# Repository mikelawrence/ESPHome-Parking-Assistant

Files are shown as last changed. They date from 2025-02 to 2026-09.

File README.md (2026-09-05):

# ESPHome Parking Assistant

From early on I learned that parking the car in the garage was a problem the needed to be solved. My Dad solved his problem with a piece of styrofoam hanging from the ceiling. When it touched the windshield you knew to stop. This was very important because the lawn mowing equipment was in front of the car. Crunch time was inevitable, don't ask me how I know. 

I recently moved and the problem became an issue again. Not because there was a crunch time incident but because we needed as much room as possible in front of the car. Having to get out of the car multiple times to make sure the door won't hit the car was a pain. So I did some searching on Youtube and found this [video](https://www.youtube.com/watch?v=HqqlY4_3kQ8) from ResinChem Tech. I really liked his use of a RGB LED strip to indicate position and when to stop. There is a ton of information so watch the whole video.1

***So yes this project is a complete ripoff of his idea!*** But I wanted to do several things different. First I wanted to use ESPHome. Second I really like designing my own hardware. And third I want to keep learning how to use Fusion 360 to design 3D printed stuff.

## Design Decisions

### ESP32 and ESPHome

ESPHome is closely aligned with Home Assistant. In fact they are the same company. Home Assistant uses ESPHome for some of their hardware like the [Home Assistant Voice Preview Edition](https://www.home-assistant.io/voice-pe/) or [Bluetooth Proxy](https://esphome.io/components/bluetooth_proxy.html). I chose a newer ESP32-S3 for this design which also has Bluetooth support. The newer ESP32's work better with the ESP-IDF framework as opposed to the default Arduino framework. Not everything is supported in the ESP-IDF, particularly several of the RGB LED libraries but the ESP32 RMT LED Strip library works well once you make sure have enough RMT memory allocated.

### USB-C Power Delivery

I liked the idea of using RGB LED Pixels since ESPHome supports these directly without custom code. I wanted a flexible power supply for driving the RGB LED Pixels both in the power capacity and voltage. I've been using a MagWLED driver for driving RGB LED pixels for a while now and I really like it's approach to using USB-C PD (Power Delivery) to select between 5V and 12V. The USB-C PD 2.0/3.0 specification supports currents greater than 3A but will need a USB-C Power Cable with E-Marker and a USB-C PD Power Source that supports these higher currents. I went with the simpler and more supported max 3A. The USB-C PD 2.0/3.0 specification will negotiate several fixed voltages at 3A: 5V-15W, 9V-27W, 12V-36W, 15V-45W and 20V-60W. 12V-36W PD is less common in chargers but 9V-27W is always available. 12V RGB LED Pixels will usually run on 9V, the difference in LED brightness is not that noticeable and may make your LED live longer. To handle the USB-C PD negotiation I chose the STUSB4500 from ST Microelectronics. This guy will support negotiate all of the USB-C PD 2.0/3.0 specification but this design will support only the following: 5V-15W, 9V-27W or 12V-36W. The STUSB4500 will be configured to support 12V-36W with a fallback of 9V-27W or just 5V-15W

The STUSB45000 will negotiate 20V by default if the USB-C PD Power Source supports it so our power supplies must support an input voltage range of 5V - 20V. The STUSB4500 uses an external pass transistor to enable V<sub>BUS</sub> at higher currents and voltages when PD is properly negotiated. Until the configured PD is properly negotiated this pass transistor is turned off. Using USB-C PD to provide a variable input voltage from USB-C PD is elegant but if 9V-27W or 12V-36W PD is configured 3.3V is still needed for the ESP32 and 5V for the TFMini. This means two DC/DC converters are necessary, one 3.3V @ 600mA to support primarily the ESP32-S3 chip and 5V @ 1.0A primarily for the TFMini Plus sensor. 

The 3.3V power supply will always have an input voltage greater than 3.3V. I could use a linear regulator but I wanted to get more experience designing efficient DC/DC converters so I chose the TPS560430 SIMPLE SWITCHER® 4-V to 36-V, 600-mA Synchronous Step-Down Converter. The 3.3V power supply is connected directly to the USB connector and will power the ESP32-S3 immediately. If you connect this board to a older USB 2.0 power source you may only get 5V at 500mA. This is enough to get the ESP32-S3 running without violating the 500mA max requirement.

For the 5V @ 1A power supply it's input voltage can be 5V so a regular step-down will not work. I chose the TPS552872, 36-V, 4-A, Fully Integrated Buck-boost Converter also from TI. This converter will switch to boost mode when the input voltage is 5V and still operate correctly. This power supply must be connected to the V<sub>BUS</sub> pass transistor and not directly to the V<sub>BUS</sub> on the USB connector. Doing so would exceed the 500mA maximum when connected to a USB 2.0 power source. Some USB 2.0 Power Sources support more than 500mA but the specification states 500mA maximum. So until PD is properly negotiated the V<sub>BUS</sub> to the RGB LED pixels and the 5.V power supply are not enabled.

An INA228 85-V, 20-Bit, Ultra-Precise Power/Energy/Charge Monitor With I2C Interface device is used to monitor both energy and power consumption. Energy consumption is a better metric than instantaneous power for understanding actual device usage. Just look at what the power company uses to bill you (kWh).

### TFMini Plus

ResinChem Tech compared multiple distance sensors in his video. He settled on the TFMini-S sensor. I also chose a TFMini sensor but went with the TFMini Plus because it was in a more durable package with a lens cover. The spot size is different but in my tests this sensor worked just fine. This sensor can use a UART or I2C interface. The default UART interface can be set to automatically send measurements at a specified rate while the I2C must be setup with a UART command first and requires polling. The TFMini Plus requires 5V power but uses 3.3V logic levels.

### RGB LED pixel interface

This board only supports RGB LED pixels that have a single data line for communication. SPI pixels are NOT supported. RGB LED pixels requires 5V logic level on the data and while many will tell you that it will work just fine with 3.3V logic I prefer to be more conservative. After doing some [research](https://electricfiredesign.com/2021/03/12/logic-level-shifters-for-driving-led-strips/) I chose the TC4427V MOSFET Driver. It can source/sink 1.5A; definatley help long cable runs. Note the V temperature range option. The V option does more that expand the temperature range it also lowers V<sub>IH</sub> from 2.4V to 2.0V. This give plenty of margin for 3.3V ESP32 with a worst case V<sub>OH</sub> of 0.8\*VCC or 0.8\*3.0=2.4V.

## Enclosure

The enclosure is designed to mount on [Elfa](https://www.containerstore.com/s/elfa/garage-plus-by-elfa/garage-plus-by-elfa-predesigned-spaces/garage-plus-7-tier-6-wall-shelving-solution/123d?productId=11023646) wire shelving. I used [Autodesk Fusion](https://www.autodesk.com/products/fusion-360/overview) to design this enclosure. I'm a novice with this tool but I'm always looking to improve. For this design I tried out a few new features of Fusion, namely Rendering and Animation.

<p align="center">
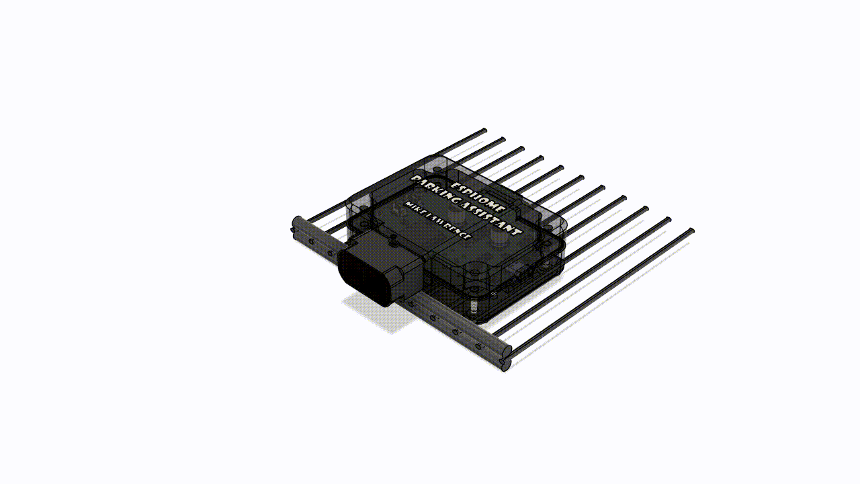
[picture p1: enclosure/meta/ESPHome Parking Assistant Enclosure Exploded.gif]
     <br />
    Exploded View of Enclosure
</p>

## PCB

This 4-layer board is designed with [KiCad](https://www.kicad.org/). I been using this free tool for a while and it just keeps getting better and better.

<p align="center">
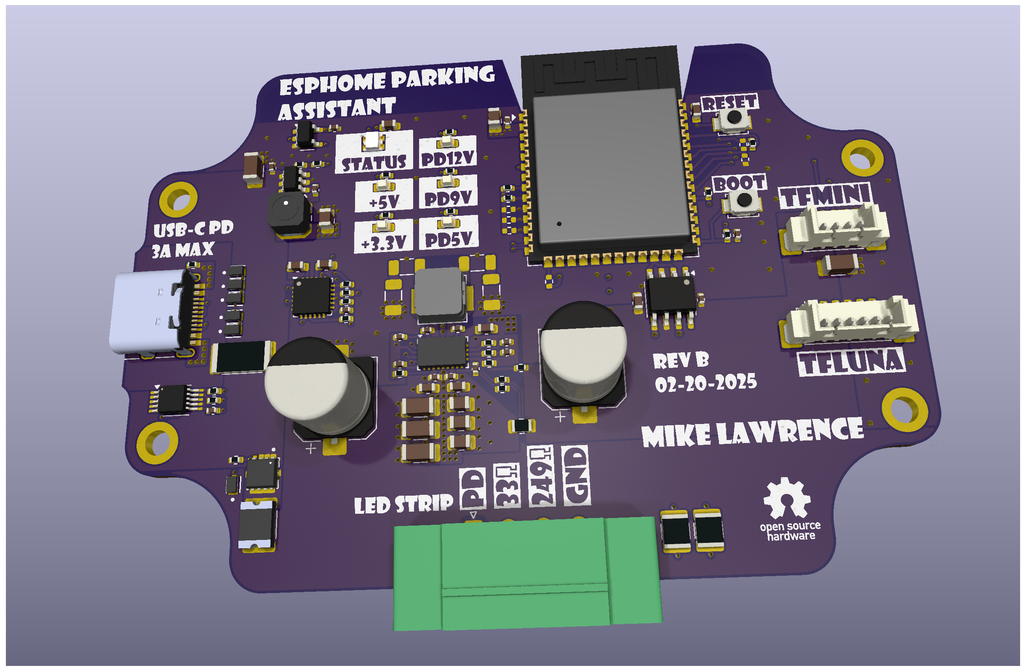
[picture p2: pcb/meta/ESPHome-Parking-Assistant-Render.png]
     <br />
    3D Render of ESPHome Parking Assistant PCB
</p>

## Operation

### LED status

There are six LEDs on the PCB to indicate status.

* **Status:** If dark something is misconfigured or damaged. If blue PS was successfully negotiated. If Power Delivery failed but +5V is available on VBUS the LED will be red. Generally you shouldn't be using the connected power brick for lighting up the LEDs unless you know it can support the power requirements. Keep in mind this board was designed for USB-C Power Delivery so why don't you connect one.
* **+5V:** Will be green when the +5V power supply is on. This power supply comes from VBUS and supports 4.5V - 22 V inputs.
* **+3.3V:** Will be green when the +3.3V power supply is on. This power supply is always on when connected to USB-C or USB 2.0 power sources. If the LED is off then the USB is not connected or there is a failure.
* **PD5V:** Will be blue when PDO1 (+5V) has been negotiated.
* **PD9V:** Will be blue when PDO2 (+9V) has been negotiated.
* **PD12V:** Will be blue when PDO3 (+12V) has been negotiated.

> [!NOTE]
> Only one of the three PD LEDs will be lit at a time. 

### Connecting RGB LED strips

The mate to the on-board terminal strip connector is Phoenix Contact 1847071.

The LED connector has 4 wires.

* **PD**: This is the LED voltage wire, often labeled 12V+ or 5V. This PCB supports up to 3A at 5V, 9V or 12V as long as the correct USB-C PD Power Source is connected.
* **33Ω**: This is data line with a 33Ω series resistor. Use this for longer wire runs over 10ft.
* **249Ω**: This is the same data line but with a 249Ω series resistor. Use this for shorter wire runs.
* **GND**: This is minus side of the LED voltage.

> [!NOTE]
> Connect only one of 33Ω or 249Ω to your LED Strip.
> [!NOTE]
> Many 12V RGB LEDs run just fine on 9V. In fact running at 9V may extend their life expectancy.

## Configuration

### STUSB4500 Configuration

> [!CAUTION]
> When configuring the STUSB4500 for the first time you should realize its default configuration will allow up to 20V on V<sub>BUS</sub>. This PCB works fine with 20V but this voltage is passed to the LED connector. Make sure your LEDs are disconnected before configuring the STUSB4500.

1. Uncomment either the 12V LED section or the 5V LED section in the ```config.yaml``` file.
2. Uncomment ```flash_nvm: true``` in the ```config.yaml``` file
   You should see the following messages in your log.

     ```log
     [00:10:03][C][stusb4500:112]: STUSB4500:
     [00:10:03][E][stusb4500:119]:   NVM has been flashed, power cycle the device to reload NVM
     ```

   If you forgot to uncomment ```flash_nvm: true``` to the configuration you will see an error in the log.

     ```log
     [00:06:27][C][stusb4500:112]: STUSB4500:
     [00:06:27][E][stusb4500:114]:   NVM does not match current settings, you should set flash_nvm: true for one boot
     [00:06:27][C][stusb4500:130]:   PDO3 negotiated 20.00V @ 1.00A, 20.00W
     ```

3. Power cycle your board. Make sure ```NVM matches settings``` is present in the log and that one of your PDOs was negotiated. The example below shows the result of the 12V LED configuration.

   ```log
   [00:00:19][C][stusb4500:112]: STUSB4500:
   [00:00:19][C][stusb4500:116]:   NVM matches settings
   [00:00:19][C][stusb4500:130]:   PDO3 negotiated 12.00V @ 3.00A, 36.00W
   ```

4. If you selected the 12V LED config section you should see either the PD12V LED or PD9V LED lit. PD5V should be lit if you selected the 5V LED section. 

5. The STUSB4500 component does check to see that the NVM is indeed different before flashing the NVM but it is prudent to remove the ```NVM matches settings``` after it is clear the STUSB4500 is working as intended. You don't want to wear out your NVM.

### Installation

Place the enclosure so the the sensor hits as flat an area as possible. For my car this is the license plate. You may have to play different options for best performance. My experience was pretty much place and forget. It just

Now the sensor is placed, close the garage door with no car present. Home Assistant will show the measured distance. Convert to cm if necessary and subtract half of ```door_tolerance``` set ```door_distance``` to this value.

Next we set ```start_distance``` to ```door_distance``` - 25 and install the current config.

For the final setting, open the garage door and park your car where you want it. Set ```stop_distance``` using the converted distance, if necessary, from Home Assistant and again install the current config.

You now have a basic setup. Testing is in order. Back the car first and then start moving back in. Watch the LED strip light turn on and start movig toward the center as you move the car in. Stop as soon as the LED strip light turn green. Check the parking position and adjust ```stop_distance``` a little bit. As you repeat this test you will get a feel for how much to change ```stop_distance``` to get the car to stop in the right place.

## Status

* PCB Rev B: Fabricated by JLCPCB and tested. The 5V DC/DC converter issues for Rev A are resolved. This board is fully operational.
* PCB Rev A: Fabricated by JLCPCB and tested. Worked well enough to write the code for ESPHome including the new STB4500 and TFMini components. The main problem with Rev A was the 5V DC/DC converter won't start at 5V. This was technically in the datasheet but there was also a minimum operating voltage the was well below 5V input. I didn't realize that you need to apply more than 5V for the regulator to start working and then you can lower the input to 5V. Not exactly what I needed.
* Enclosure: Printed and successfully tested on Rev A. Rev B has been fully tested.

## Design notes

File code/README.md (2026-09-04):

# ESPHome Parking Assistant Code

Use the ```config.yaml``` file above to configure the ESPHome Parking Assistant in ESPHome.

## STUSB4500 and TFMini External Components

ESPHome doesn't directly support either the STUSB4500 or the TFMini devices. I wrote code that allows ESPhome to support these devices using [External Components](https://esphome.io/components/external_components.html).

For a more detailed description of these components have a look at the repositories [TFMini](https://github.com/mikelawrence/esphome-component-tfmini) and [STUSB4500](https://github.com/mikelawrence/esphome-component-stusb4500).

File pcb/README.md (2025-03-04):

# ESPHome Parking Assistant PCB
<p align="center">
     <br />
</p>

The PCB is designed in [KiCad](https://www.kicad.org/). Fabrication and Assembly is tuned toward [JCLPCB](https://jlcpcb.com/). The production folder has everything you need for JLCPCB to send you fully assembled boards.

## Schematic
<p align="center">
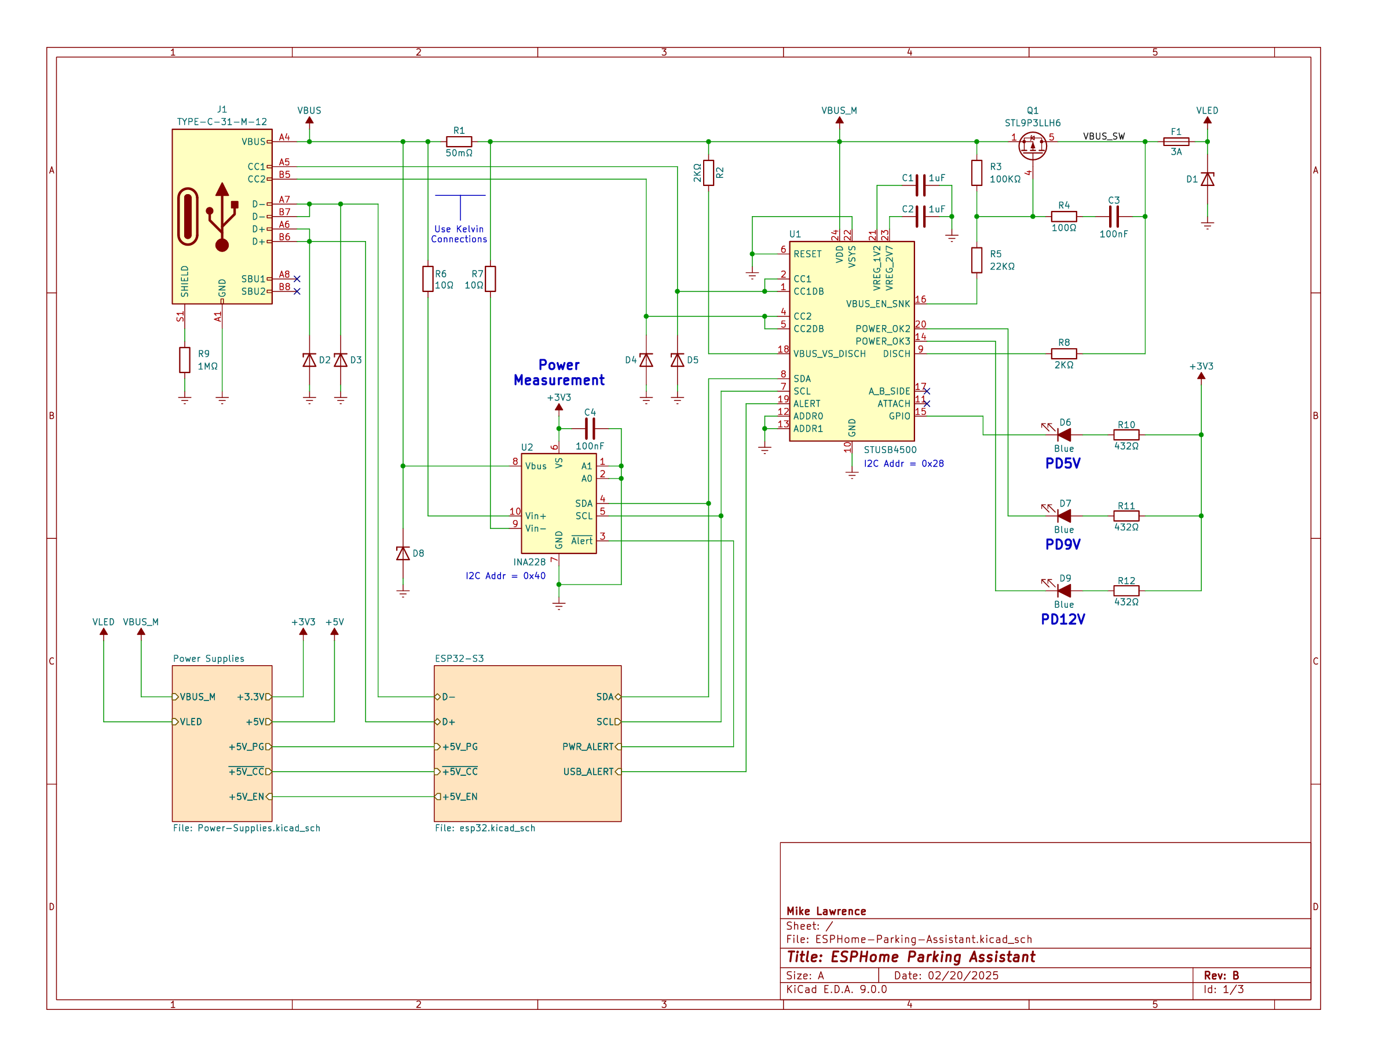
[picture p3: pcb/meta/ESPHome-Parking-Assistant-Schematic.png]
     <br />
</p>

### Do Not Populate (DNP) Notes
* ```C9```, ```C10```, ```R16``` and ```R17```: These components are an optional snubber used to reduce EMI. Not needed.
* ```R31``` and ```R32``` are pullups for open drain outputs. If these pins are used the 10K pullup will be enabled on the ESP32 input pins.
* ```R33``` and ```R35``` are pullups for the I<sub>2</sub>C Bus. By default the internal ESP32 pullups are enabled.
* ```R34``` and ```R36``` can be used to pullup or pulldown the ```CONFIG``` pin on the TFLuna connector. For now this is not necessary because the code only supports the UART interface on the TFLuna and leaving ```CONFIG``` floating will enable the UART. 
* ```R26``` is used to compensate for cable droop. Not currently used.

## Bill of Materials
<p align="center">
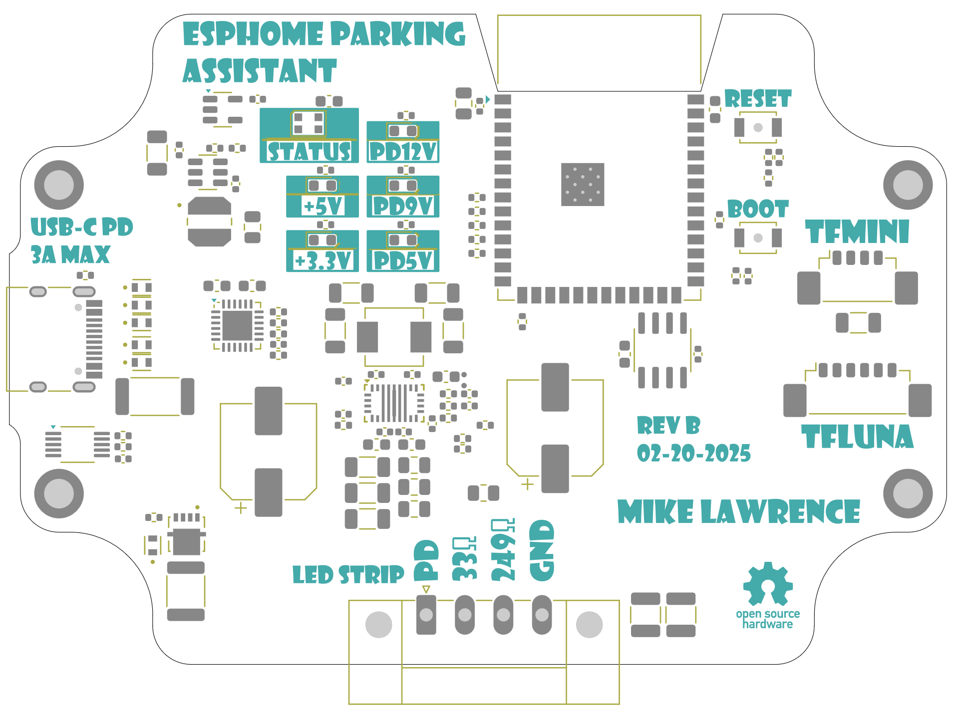
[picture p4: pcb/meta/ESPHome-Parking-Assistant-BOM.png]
     <br />
    Interactive BOM
</p>

## PCB Info
* 4 layer to support an additional ground plane and signal layer to reduce plane interruptions on the outer layers.
* Dimension are 85mm X 59mm.
* Requires oven reflow or hot air to assemble some components.
* Supports TFMini Plus, TFMini-S and TFLuna Range Finder Sensors. Enclosure is designed for TFMini Plus Sensor.

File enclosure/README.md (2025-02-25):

# ESPHome Parking Assistant Enclosure

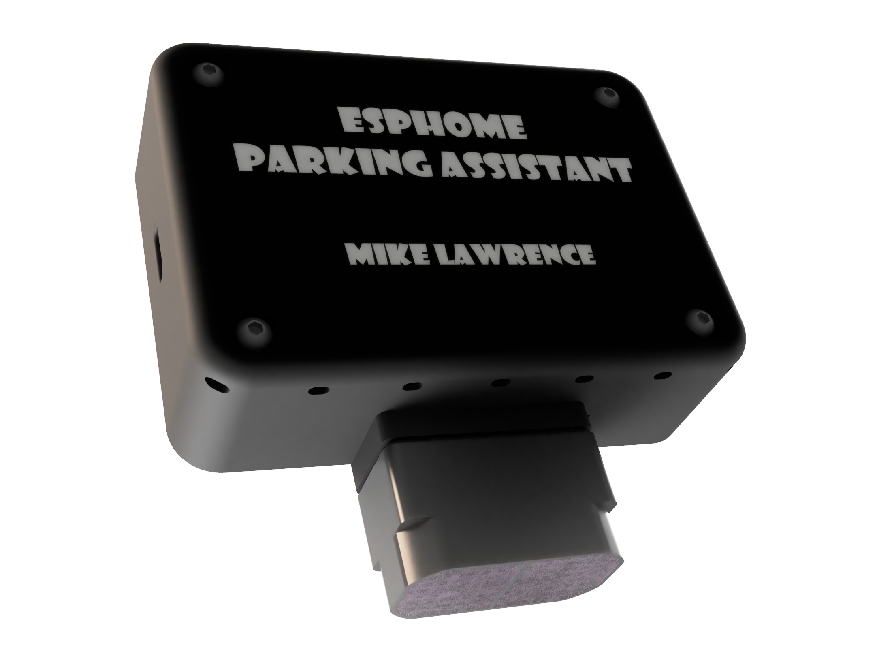
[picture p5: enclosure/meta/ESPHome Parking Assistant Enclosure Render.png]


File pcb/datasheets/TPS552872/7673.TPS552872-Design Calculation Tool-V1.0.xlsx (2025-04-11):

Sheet: Design Calculation
Design Tool for TPS552872
V1.0 (08/01/2023)
This tool is designed to aid the user in designing the TPS552872 buck-boost converter. Refer to TPS552872 datasheet for detail design precedure and all equations.
 |  | User input value
 |  | Calculated value
 |  | No use or internal value
Description | Value | Units | Instructions/Comments | Schematic
Component Value
Vin(min) | 4.5 | V | >=3.0V
Vin(max) | 22 | V | <=36V
Vout | 5.00 | V | Must be lower than or equal to 22V
Iout(max) | 1.5 | A | Maximum output current
VCC | Internal |  | Select internal VCC or use external VCC power supply
EXTVCC | High |  | EXTVCC pin input logic status
Switching Mode at light load | FPWM |  | Select Forced PWM or Auto PFM mode at light load
MODE | High |  | MODE pin input logic status
R5 recommended | 100000.0 | Ω | Up resistor value of the extenral feedback resistor value. It is recommended to 100kΩ
R6 recommended | 31578.9 | Ω | Bottom resistor value of the external feedback resistor divider
Iout(limit) | 2 | A | Output current limit setting
R1 | 25.0 | mΩ | Output current sensing resistor
ΔIout(Cout_rms) | 0.50 | Arms | The equivalent output capacitor current ripple spec must be higher than this value.
ΔIin(Cin_rms) | 0.75 | Arms | The equivalent input capacitor current ripple spec must be higher than this value
f(sw) | 403000 | Hz | Typical switching frequency
R2 recommended | 48677.79156 | Ω | Switching frequency setting resistor
Frequency dithering f(mod) | 725 | Hz | Modulation frequency for spread spectrum
C8 recommended | 1.011982717e-08 | F |  | Register Setting
ΔVout(pk-pk) | 0.05 | Vpp | Maximum desired output ripple solely due to output capacitance (ignores ESR)
Cout(min) recommended | 7.444168734e-06 | F | Minimum output capacitance needed for Vout ripple requirement
C2 actual | 3.3e-05 | F | Effective ceramic capacitance at VOUT. Need to consider the derating with DC bias voltage
C3 actual | 0.000189 | F | Effective electrolytic capacitance. Need to consider the derating with DC bias voltage
ESR of C3 | 0.185 | Ω | Equivalent ESR if multiple high ESR electrolytic capacitors in parallel
ΔVin(pk-pk) | 0.05 | Vpp | Maximum desired input ripple due to solely to input capacitance at buck mode
Cin(min) recommended | 1.861042184e-05 | F | Minimum input capacitance needed for Vin ripple requirement
Cin actual | 2.3e-08 | F | effective output capacitance. Need to consider the derating with DC bias voltage when using ceramic cap
η estimate | 95.0% |  | Efficiency estimate. Correct it after getting the calculated efficiency
K | 0.5 |  | Fraction of maximum average inductor current that is ripple current (0.2-0.6 typically)
L1 recommended min | 1.272952854e-06 | H | L1's minimum recommended inductance value to meet inductor current ripple ratio at boost mode with Vin_min
L1 actual | 4.7e-06 | H
I(Lrms) max | 1.76 | Arms | Inductor maximum RMS current
I(Lpeak) max | 1.87 | A | The inductor (L1) is recommended to have saturation current rating 30% higher than this value.
I(Laverage) max | 1.75 | A | Inductor average current at minimum Vin.
I(Lvalley) max | 1.64 | A
Average Inductor Limit | 4.0 | A | Desired typical average inductor current limit. ±0.7A tolerance
External CDC voltage ratio | 0 | mV/mV | ΔVout / (VISP-VISN)
R4 recommend | floating | Ω | Recommended R4 for external CDC setting
Loop Compensation Calculation in FPWM CCM mode |  |  |  | Bode Plot
Vin | 12.0 | V | Check both buck and boost mode by changing Vin and Vout. The loop must have enough phase margin and gain margin
Vout | 5.0 | V
Buck or Boost? | Buck |  | Calculate open loop compensate at buck mode or boost mode
gm_PS | 17.6 | S | Power stage gm of IL/Vcomp
fp_PS | 215.0742474 | Hz | Power stage pole of Rload and Cout
fz_RHP | No RPHZ | Hz | Right half plane zero in boost mode
fz_ESR | 4551.835924 | Hz | ESR zero of the output cap
f(BW) desired | 10000 | Hz | Should be less than 1/5*fzRPH and 1/10*fsw
gm_EA | 0.00019 | S | Error amplifier gm
R3 recommended | 18473.22145 | Ω
R3 actual | 15000 | Ω | COMP pin has internal 2k resistor in seriese with R3
C7 recommended | 9.362055476e-09 | F | Set the compensation fz = fco/10
C7 actual | 1e-08 | F
fz_COMP | 936.2055476 | Hz | Loop compensation zero frequency
C6 recommended | 3.039509714e-09 | F | The lower zero of the Cout's ESR zero and boost right half plane zero should be cancelled by the R3*(C6*C7/(C6+C7)) pole.
C6 actual | 2.7e-09 | F
fp2_COMP | 4399.78508 | Hz | Have internal 3pF cap between COMP and GND
Efficiency in buck CCM mode or boost CCM mode with maximum Iout
Vin | 5.0 | V | Vin for efficiency estimation at desired Vout and Iout(max)
I(Lrms) | 1.50 | A | Inductor RMS current
I(Lpeak) | 1.50 | A | Inductor peak current
I(Lvalley) | 1.50 | A | Inductor valley current
DCR of L1 | 0.071 | Ω | Inductor series resistance per inductor datasheet
Buck HSFET Rdson | 0.014 | Ω | Buck HSFET on-resistance in TPS552892 is 14mΩ at 25°C. Temperature coefficient is 0.4%/°C. Correct it when at high Tj
Buck HSFET rise time | 1.3e-08 | s | Estimate of SW1 node 10-90% rise time from measurement
Buck HSFET fall time | 1.3e-08 | s | Estimate of SW1 node 10-90% fall time from measurement
Buck LSFET Rdson | 0.022 | Ω | Buck LSFET on-resistance in TPS552892 is 22mΩ at 25°C. Temperature coefficient is 0.4%/°C. Correct it when at high Tj
Buck LSFET dead time | 1e-08 | s | Dead time during the switching
Buck LSFET diode voltage | 0.8 | V | Estimate of body diode voltage of the HSFET
Boost LSFET Rdson | 0.011 | Ω | Boost LSFET on-resistance in TPS552892 is 11mΩ at 25°C. Temperature coefficient is 0.4%/°C. Correct it when at high Tj
Boost LSFET fall time | 9e-09 | s | Estimate of SW node 10-90% fall time from measurement
Boost LSFET rise time | 1.3e-08 | s | Estimate of SW node 10-90% rise time from measurement
Boost HSFET Rdson | 0.01 | Ω | Boost HSFET on-resistance in TPS552892 is 10mΩ at 25°C. Temperature coefficient is 0.4%/°C. Correct it when at high Tj
Boost HSFET dead time | 2e-08 | s | Dead time during the switching
Boost HSFET diode voltage | 1.0 | V | Estimate of body diode voltage of the HSFET
Buck snubber Csnubber | 0 | F | Capacitance of snubber at buck side
Boost snubber Csnubber | 0 | F | Capacitance of snubber at boost side
Rpcb on power path | 2.0 | mΩ | PCB trace resistance on power path from Vin to Vout cap
Rpcb Pd | 4.5 | mW | Power losses on PCB trace
Inductor DCR Pd | 159.75 | mW | Includes losses from DC resistance drop only
Inductor core & AC Pd | 521 | mW | Core and AC loss of inductor. Use inductor vendor's formula to estimate. 521mW is the power loss of XAL7070-472 running at 400kHz with Ilrms=5.32A and Ilripple=2.63A at 400kHz.
TPS552892 Pd | 145.831992 | mW | Power loss on TPS552892
Rsense Pd | 56.25 | mW | Power loss on output current sense resistor
Snubber Pd | 0 | mW | Power loss on snubber
Cout Pd | 0 | mW | Power loss on ESR of the output capacitor in boost mode | 5.1975e-06 | 0 | 0
η - calculated | 89.4% |  | Efficiency at Iout_max
ΘJA | 33 | °C/W | TPS552892 junction to ambient thermal resistance on EVM. The actual ΘJA depends on the PCB design.
TPS552892 temperature rise | 4.8 | °C | The top case temperature of IC is very close to the Junction temperature because ΨJT=0.6°C/W

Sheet: LegalDisclaimer
THIS PROGRAM IS PROVIDED "AS IS". TI MAKES NO WARRANTIES OR REPRESENTATIONS, EITHER EXPRESS, IMPLIED OR STATUTORY, INCLUDING ANY IMPLIED WARRANTIES OF MERCHANTABILITY, FITNESS FOR A PARTICULAR PURPOSE, LACK OF VIRUSES, ACCURACY OR COMPLETENESS OF RESPONSES, RESULTS AND LACK OF NEGLIGENCE. TI DISCLAIMS ANY WARRANTY OF TITLE, QUIET ENJOYMENT, QUIET POSSESSION, AND NON-INFRINGEMENT OF ANY THIRD PARTY INTELLECTUAL PROPERTY RIGHTS WITH REGARD TO THE PROGRAM OR YOUR USE OF THE PROGRAM.
IN NO EVENT SHALL TI BE LIABLE FOR ANY SPECIAL, INCIDENTAL, CONSEQUENTIAL OR INDIRECT DAMAGES, HOWEVER CAUSED, ON ANY THEORY OF LIABILITY AND WHETHER OR NOT TI HAS BEEN ADVISED OF THE POSSIBILITY OF SUCH DAMAGES, ARISING IN ANY WAY OUT OF THIS AGREEMENT, THE PROGRAM, OR YOUR USE OF THE PROGRAM. EXCLUDED DAMAGES INCLUDE, BUT ARE NOT LIMITED TO, COST OF REMOVAL OR REINSTALLATION, COMPUTER TIME, LABOR COSTS, LOSS OF GOODWILL, LOSS OF PROFITS, LOSS OF SAVINGS, OR LOSS OF USE OR INTERRUPTION OF BUSINESS. IN NO EVENT WILL TI'S AGGREGATE LIABILITY UNDER THIS AGREEMENT OR ARISING OUT OF YOUR USE OF THE PROGRAM EXCEED FIVE HUNDRED DOLLARS (U.S.$500).
Unless otherwise stated, the Program written and copyrighted by Texas Instruments is distributed as "freeware". You may, only under TI's copyright in the Program, use and modify the Program without any charge or restriction. You may distribute to third parties, provided that you transfer a copy of this license to the third party and the third party agrees to these terms by its first use of the Program. You must reproduce the copyright notice and any other legend of ownership on each copy or partial copy, of the Program.
You acknowledge and agree that the Program contains copyrighted material, trade secrets and other TI proprietary information and is protected by copyright laws, international copyright treaties, and trade secret laws, as well as other intellectual property laws. To protect TI's rights in the Program, you agree not to decompile, reverse engineer, disassemble or otherwise translate any object code versions of the Program to a human-readable form. You agree that in no event will you alter, remove or destroy any copyright notice included in the Program. TI reserves all rights not specifically granted under this license. Except as specifically provided herein, nothing in this agreement shall be construed as conferring by implication, estoppel, or otherwise, upon you, any license or other right under any TI patents, copyrights or trade secrets.
TI Information - Selective Disclosure. You may not use the Program in non-TI devices.

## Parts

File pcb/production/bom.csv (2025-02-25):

Designator | Footprint | Quantity | Value | LCSC Part #
C1, C14, C2, C25, C35, C37, C39 | 0603 | 7 | 1uF | C15849
C11, C12, C13, C19, C22, C29, C3, C31, C34, C36, C38, C4, C5, C7 | 0402 | 14 | 100nF | C307331
C15, C16, C17, C32, C8 | 0805 | 5 | 22uF | C92814
C18, C23 | CP_Elec_8x10.5 | 2 | 220uF | C178562
C20, C21, C24, C33, C6 | 1206 | 5 | 10uF | C13585
C26 | 0603 | 1 | 4.7uF | C19666
C27, C30 | 0402 | 2 | 10nF | C15195
C28 | 0402 | 1 | 2.7nF | C84704
D1, D4, D5, D8 | TVS_ESDA25P35-1U1M | 4 | ESDA25P35-1U1M | C1974707
D10, D11 | 0603 | 2 | Green | C7496818
D12 | LED_WS2812B-2020_PLCC4_2.0x2.0mm | 1 | WS2812B-2020 | C965555
D2, D3 | TVS_ESDA25P35-1U1M | 2 | ESDA7P60-1U1M | C1975146
D6, D7, D9 | 0603 | 3 | Blue | C7496819
F1 | 1812 | 1 | 3A | C2760295
J1 | USB_C_Receptacle_HRO_TYPE-C-31-M-12 | 1 | TYPE-C-31-M-12 | C165948
J2 | Molex_PicoBlade_53398-0471_1x04-1MP_P1.25mm_Vertical | 1 | 533980471 | C17617036
J3 | Molex_PicoBlade_53398-0671_1x06-1MP_P1.25mm_Vertical | 1 | 533980671 | C277393
J4 | PhoenixContact_MC_1,5_4-GF-3.5_1x04_P3.50mm_Horizontal_ThreadedFlange_MountHole | 1 | Screw_Terminal_01x04
L1 | IND_VLCF4028T-100M1R0-2 | 1 | 10uH | C694593
L2 | L_Vishay_IHLP-2020 | 1 | 4.7uH | C845007
Q1 | TRANS_STL9P3LLH6 | 1 | STL9P3LLH6 | C2969828
R1 | 2512 | 1 | 50mΩ | C375690
R10, R11, R12 | 0402 | 3 | 432Ω | C25113
R13 | 0402 | 1 | 51KΩ | C25794
R14, R2, R8 | 0402 | 3 | 2KΩ | C4109
R15, R5 | 0402 | 2 | 22KΩ | C25768
R18 | 0805 | 1 | 25mΩ | C2767472
R19, R20, R6, R7 | 0402 | 4 | 10Ω | C25077
R21, R29, R3, R30, R37 | 0402 | 5 | 100KΩ | C25741
R22 | 0402 | 1 | 8.2KΩ | C36953
R23 | 0402 | 1 | 15KΩ | C25539
R24 | 0402 | 1 | 31.6KΩ | C226989
R25 | 0402 | 1 | 48.7KΩ | C26981
R27, R28 | 0402 | 2 | 10KΩ | C25531
R38 | 1210 | 1 | 33Ω | C105005
R39 | 1210 | 1 | 249Ω | C874850
R4 | 0402 | 1 | 100Ω | C25076
R9 | 0402 | 1 | 1MΩ | C26083
SW1 | SW_SPST_B3U-1000P-B | 1 | RESET | C231329
SW2 | SW_SPST_B3U-1000P-B | 1 | BOOT | C231329
U1 | QFN-24-1EP_4x4mm_P0.5mm_EP2.7x2.7mm | 1 | STUSB4500 | C2678061
U2 | VSSOP-10_3x3mm_P0.5mm | 1 | INA228 | C2887910
U3 | SOT-23-6 | 1 | TPS560430 | C524782
U4 | VQFN21_RYQ_TEX | 1 | TPS552872RYQR | C22397842
U5 | ESP32-S3-WROOM-1 | 1 | ESP32-S3-WROOM-1 | C2913201
U6 | SOIC-8_3.9x4.9mm_P1.27mm | 1 | TC4427 | C636893
U7 | SOT-23-5 | 1 | SN74LV1T34DBV | C100024

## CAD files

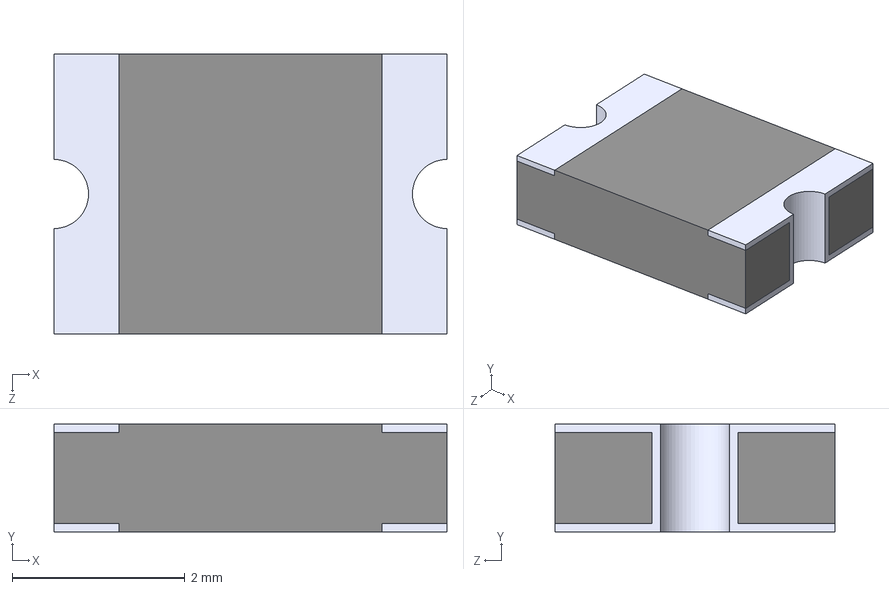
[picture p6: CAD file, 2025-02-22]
pcb/3dmodels/1812_Fuse.STEP
4.55 x 1.25 x 3.24 mm

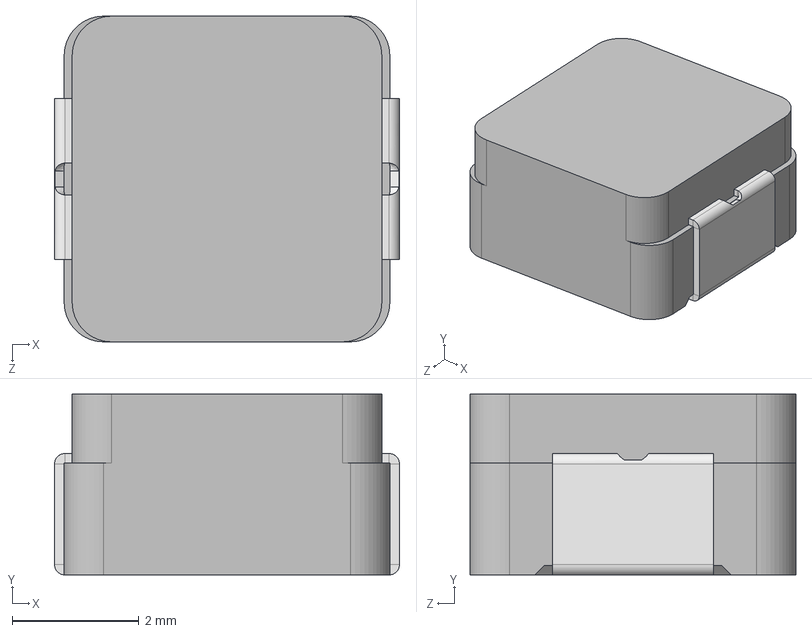
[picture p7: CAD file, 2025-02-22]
pcb/3dmodels/IHLP2020CZ.step
5.45 x 2.86 x 5.15 mm

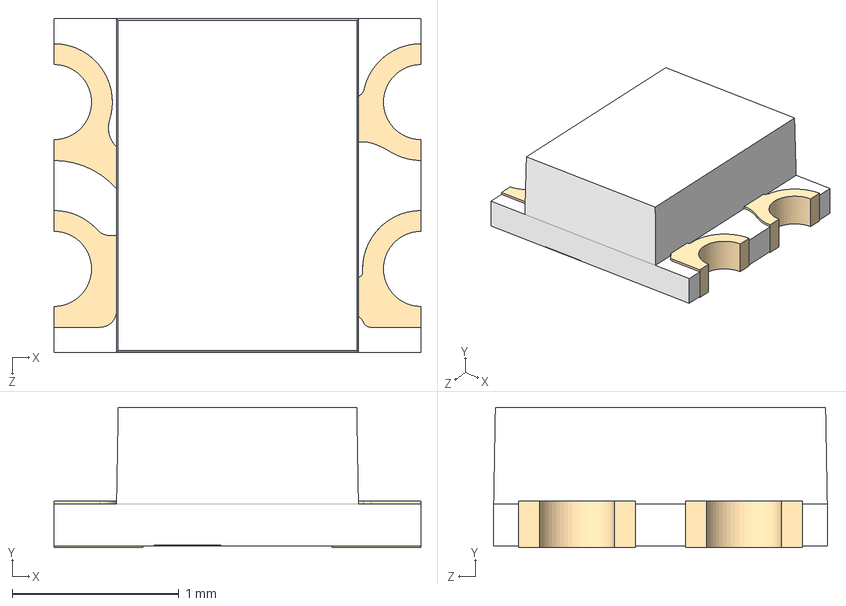
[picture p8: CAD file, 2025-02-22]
pcb/3dmodels/WS2812-2020--3DModel-STEP-1.STEP
2.20 x 0.84 x 2.00 mm

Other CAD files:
enclosure/LED Strip Mount.f3z

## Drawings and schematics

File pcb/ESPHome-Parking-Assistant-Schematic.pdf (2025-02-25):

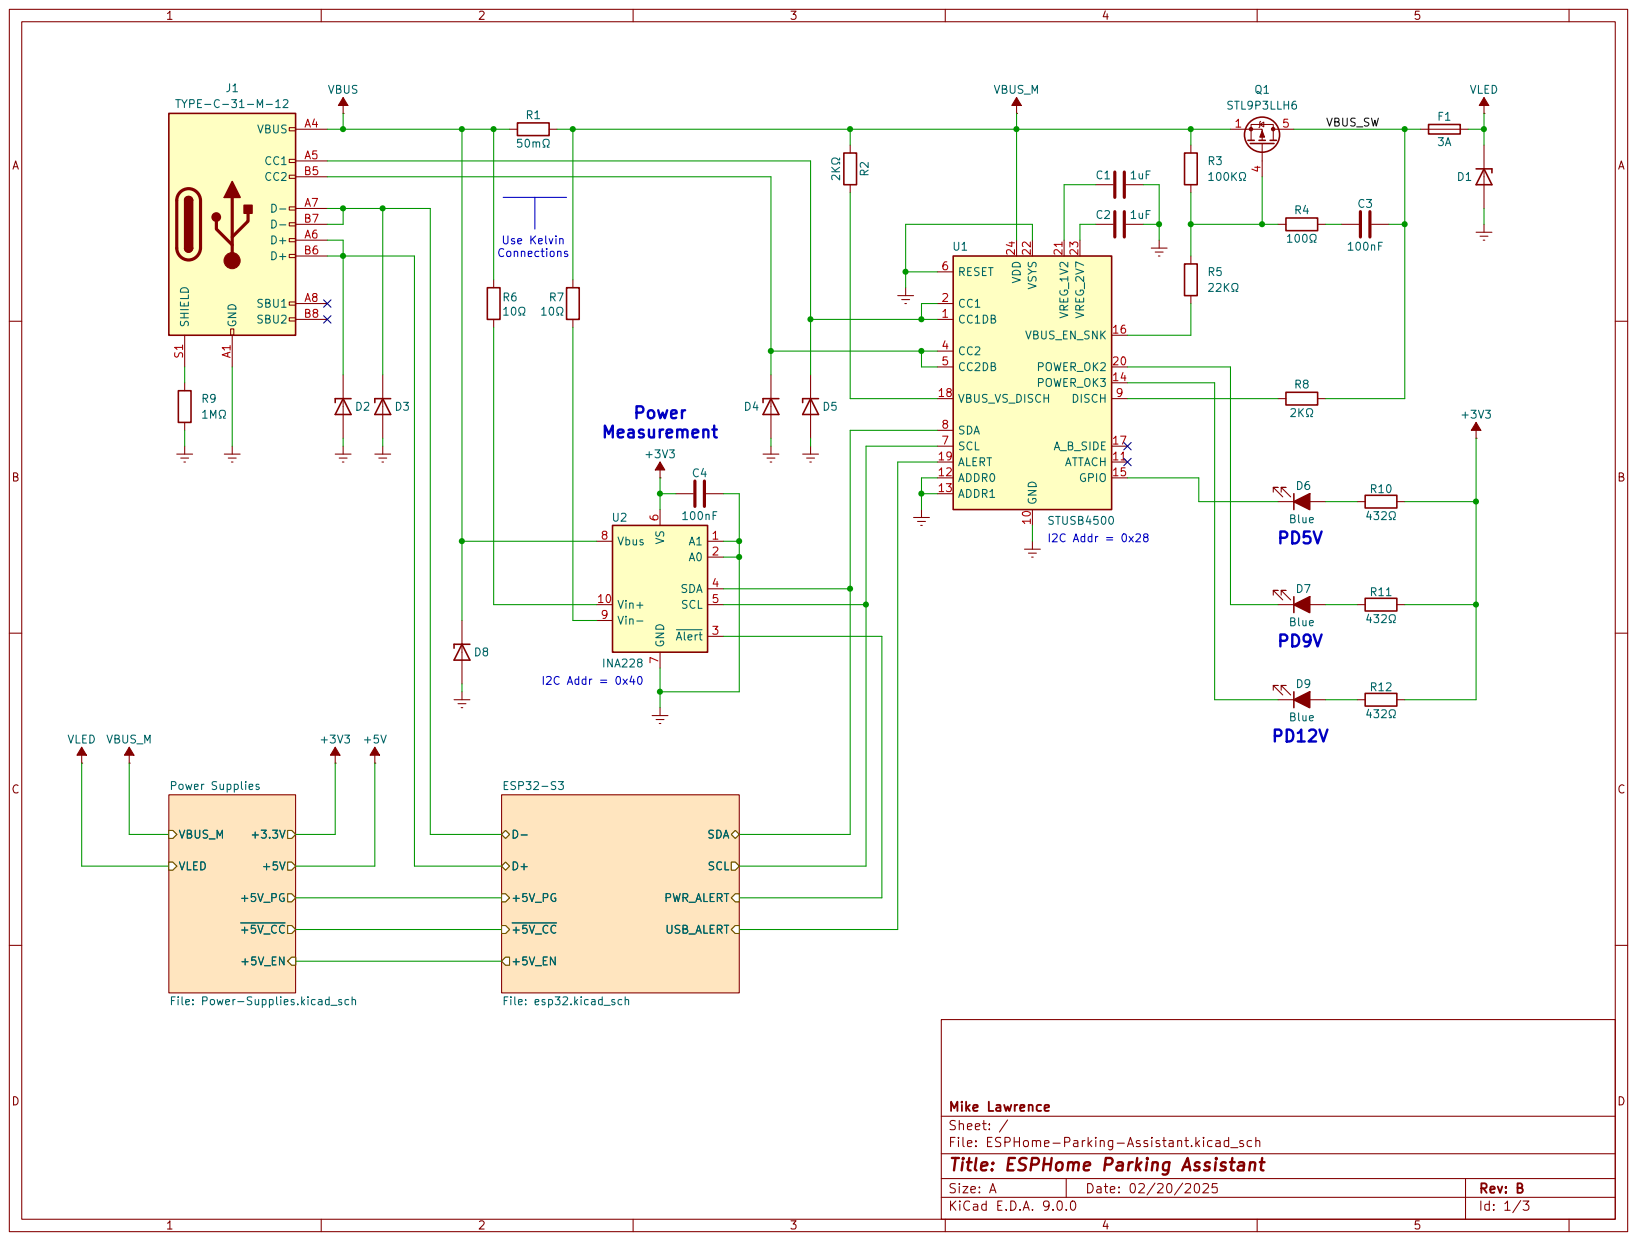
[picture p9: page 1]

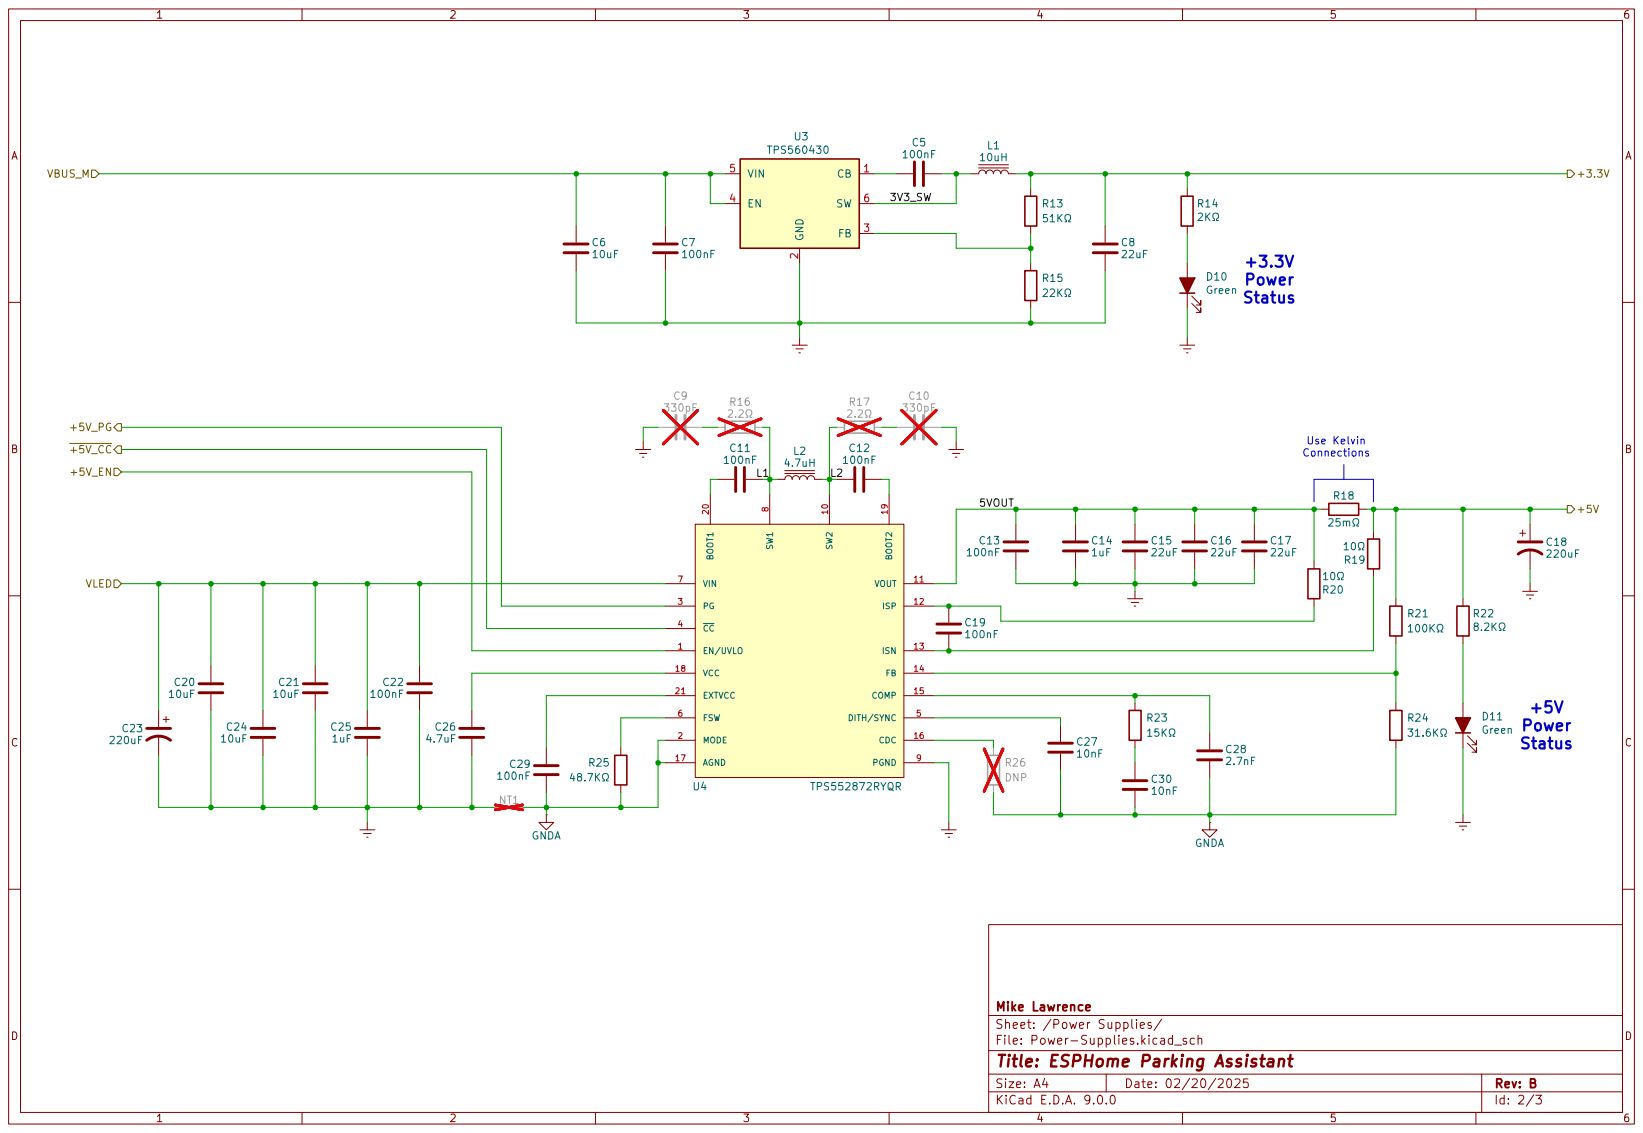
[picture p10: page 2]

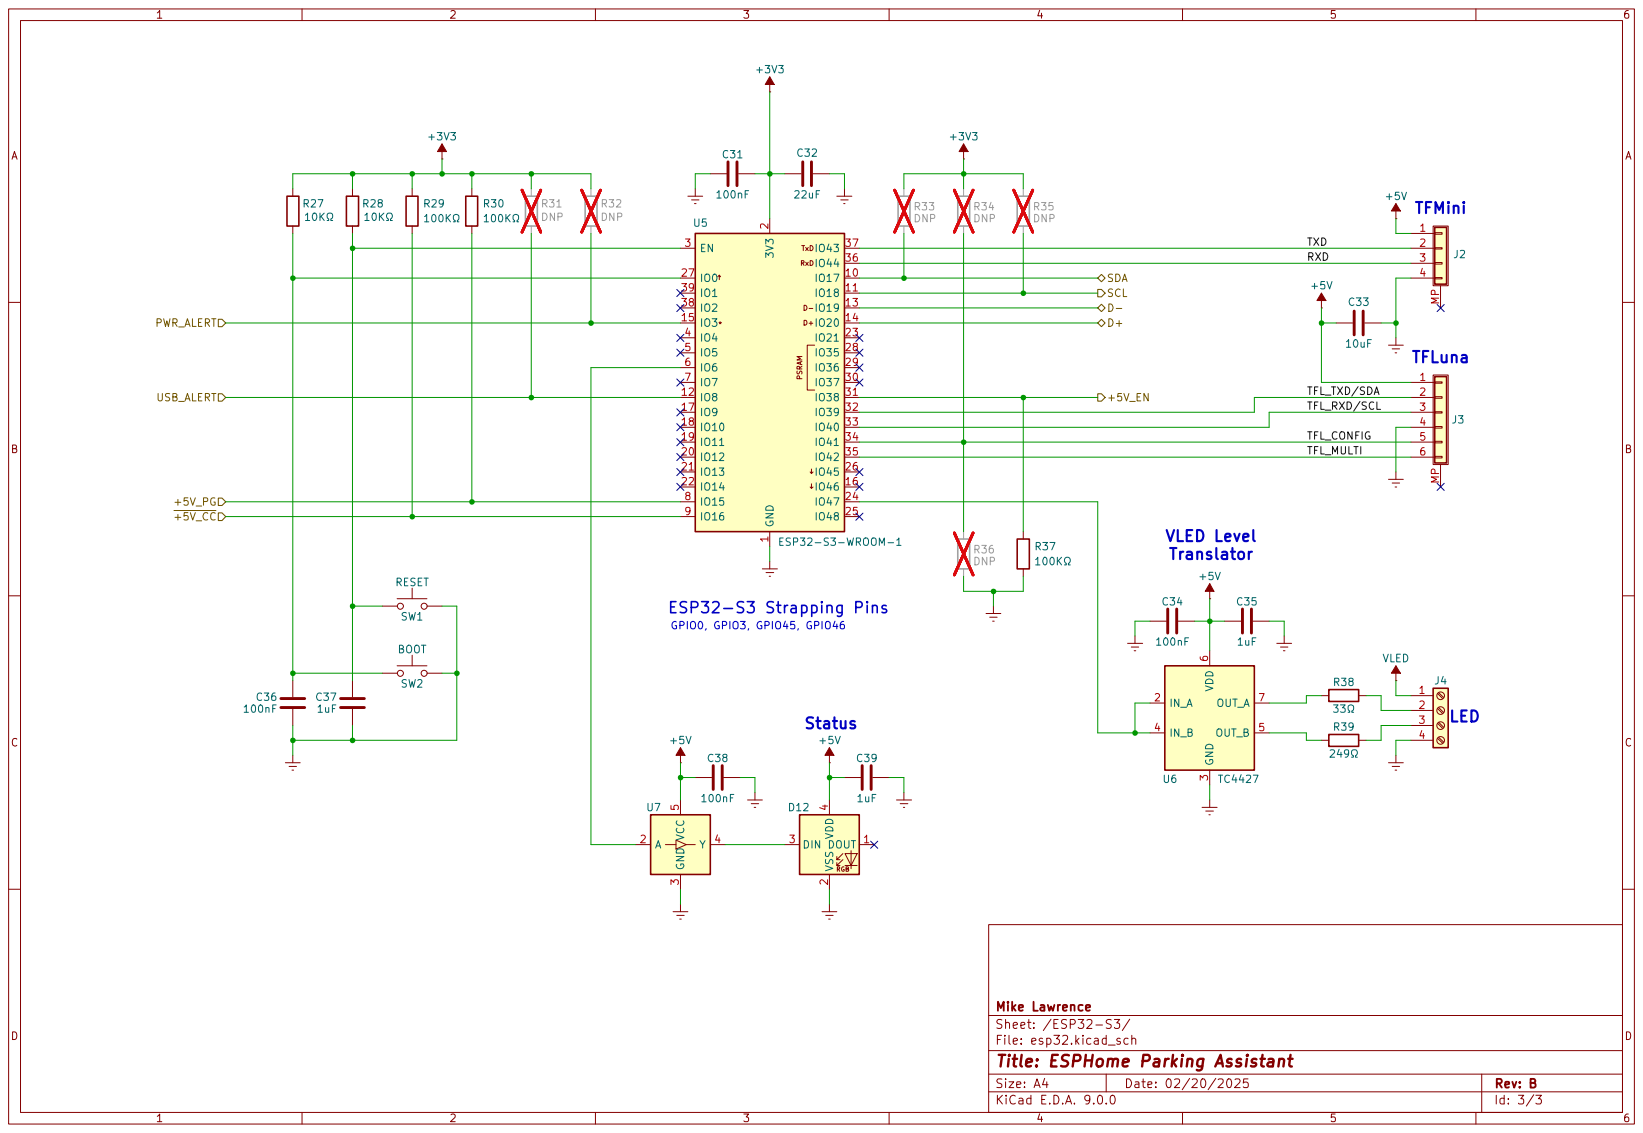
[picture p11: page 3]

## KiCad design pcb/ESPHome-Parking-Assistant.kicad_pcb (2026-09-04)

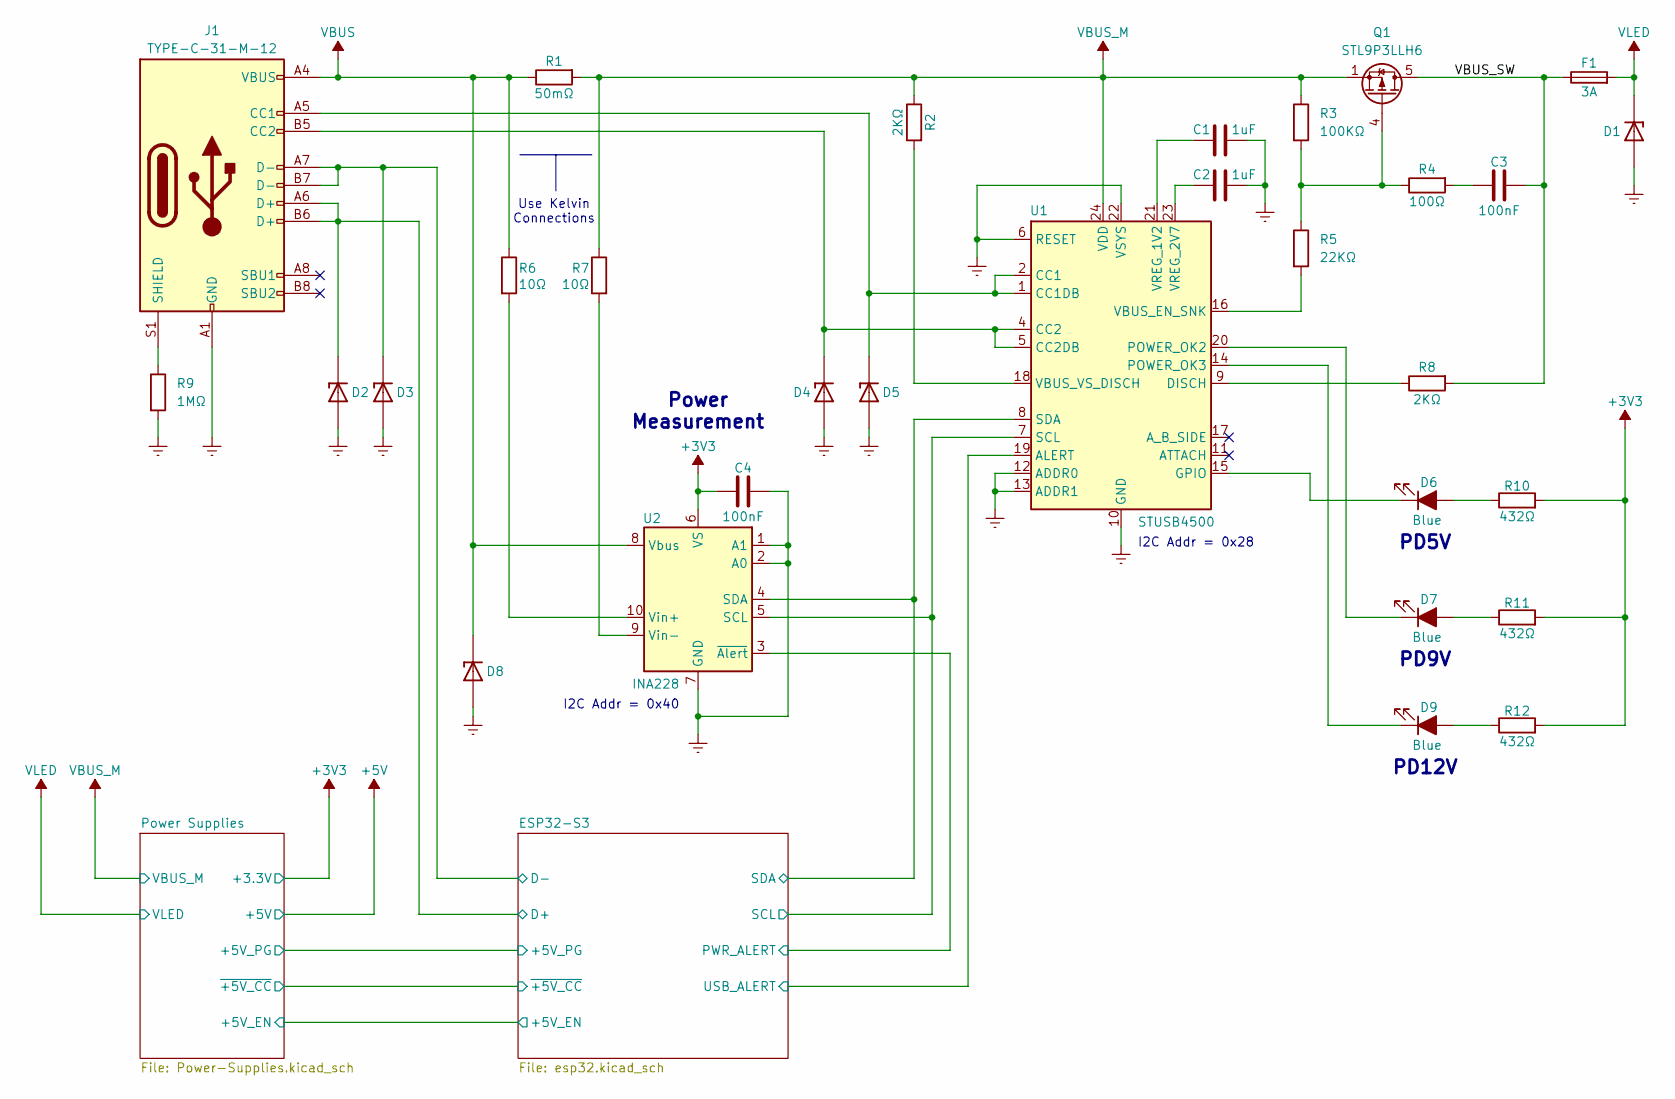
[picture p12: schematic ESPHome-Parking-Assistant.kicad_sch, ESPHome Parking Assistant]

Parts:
C1, C2: 1uF; C_0603_1608Metric; Part Number CL10A105KB8NNNC; LCSC C15849
C3, C4: 100nF; C_0402_1005Metric; Part Number CL05B104KB54PNC; LCSC C307331
D1, D4, D5, D8: ESDA25P35-1U1M; TVS_ESDA25P35-1U1M; Part Number ESDA25P35-1U1M; LCSC C1974707
D2, D3: ESDA7P60-1U1M; TVS_ESDA25P35-1U1M; Part Number ESDA7P60-1U1M; LCSC C1975146
D6, D7, D9: Blue; LED_0603_1608Metric; Part Number F.0603.00026/P2-0603B1TS2-06T-001; LCSC C7496819
F1: 3A; Fuse_1812_4532Metric; LCSC C2760295
J1: TYPE-C-31-M-12; USB_C_Receptacle_HRO_TYPE-C-31-M-12; Part Number TYPE-C-31-M-12; LCSC C165948
Q1: STL9P3LLH6; TRANS_STL9P3LLH6; Part Number STL9P3LLH6; LCSC C2969828
R1: 50mΩ; R_2512_6332Metric; LCSC C375690
R2, R8: 2KΩ; R_0402_1005Metric; LCSC C4109
R3: 100KΩ; R_0402_1005Metric; LCSC C25741
R4: 100Ω; R_0402_1005Metric; LCSC C25076
R5: 22KΩ; R_0402_1005Metric; LCSC C25768
R6, R7: 10Ω; R_0402_1005Metric; LCSC C25077
R9: 1MΩ; R_0402_1005Metric; LCSC C26083
R10, R11, R12: 432Ω; R_0402_1005Metric; LCSC C25113
U1: STUSB4500; QFN-24-1EP_4x4mm_P0.5mm_EP2.7x2.7mm; Part Number STUSB4500QTR; LCSC C2678061
U2: INA228; VSSOP-10_3x3mm_P0.5mm; Part Number INA228AIDGSR; LCSC C2887910

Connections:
+3V3: C4.2, R10.2, R11.2, R12.2, U2.6 (VS); also elsewhere on the board
/ESP32-S3/D+: D2.C, J1.A6 (D+), J1.B6 (D+); also elsewhere on the board
/ESP32-S3/D-: D3.C, J1.A7 (D-), J1.B7 (D-); also elsewhere on the board
/ESP32-S3/PWR_ALERT: U2.3 (~Alert); also elsewhere on the board
/ESP32-S3/SCL: U1.7 (SCL), U2.5 (SCL); also elsewhere on the board
/ESP32-S3/SDA: U1.8 (SDA), U2.4 (SDA); also elsewhere on the board
/ESP32-S3/USB_ALERT: U1.19 (ALERT); also elsewhere on the board
/VBUS_SW: C3.2, F1.1, Q1.5 (D), R8.2
GND: C1.1, C2.1, C4.1, D1.A, D2.A, D3.A, D4.A, D5.A, D8.A, J1.A1 (GND), J1.A12 (GND), J1.B1 (GND), J1.B12 (GND), R9.2, U1.6 (RESET), U1.10 (GND), U1.12 (ADDR0), U1.13 (ADDR1), U1.22 (VSYS), U1.25 (GND), U2.1 (A1), U2.2 (A0), U2.7 (GND); also elsewhere on the board
unnamed: C3.1, R4.2
unnamed: D6.2 (A), R10.1
unnamed: D6.1 (K), U1.15 (GPIO)
unnamed: D7.2 (A), R11.1
unnamed: D7.1 (K), U1.20 (POWER_OK2)
unnamed: D9.2 (A), R12.1
unnamed: D9.1 (K), U1.14 (POWER_OK3)
unnamed: D5.C, J1.A5 (CC1), U1.1 (CC1DB), U1.2 (CC1)
unnamed: D4.C, J1.B5 (CC2), U1.4 (CC2), U1.5 (CC2DB)
unnamed: J1.S1 (SHIELD), R9.1
unnamed: Q1.4 (G), R3.2, R4.1, R5.1
unnamed: R8.1, U1.9 (DISCH)
unnamed: R5.2, U1.16 (VBUS_EN_SNK)
unnamed: R2.2, U1.18 (VBUS_VS_DISCH)
unnamed: C1.2, U1.21 (VREG_1V2)
unnamed: C2.2, U1.23 (VREG_2V7)
unnamed: R6.2, U2.10 (Vin+)
unnamed: R7.2, U2.9 (Vin-)
VBUS: D8.C, J1.A4 (VBUS), J1.A9 (VBUS), J1.B4 (VBUS), J1.B9 (VBUS), R1.1, R6.1, U2.8 (Vbus)
VBUS_M: Q1.1 (S), Q1.2 (S), Q1.3 (S), R1.2, R2.1, R3.1, R7.1, U1.24 (VDD); also elsewhere on the board
VLED: D1.C, F1.2; also elsewhere on the board

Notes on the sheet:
PD9V
I2C Addr = 0x40
Use Kelvin Connections
PD5V
PD12V
Power Measurement
I2C Addr = 0x28

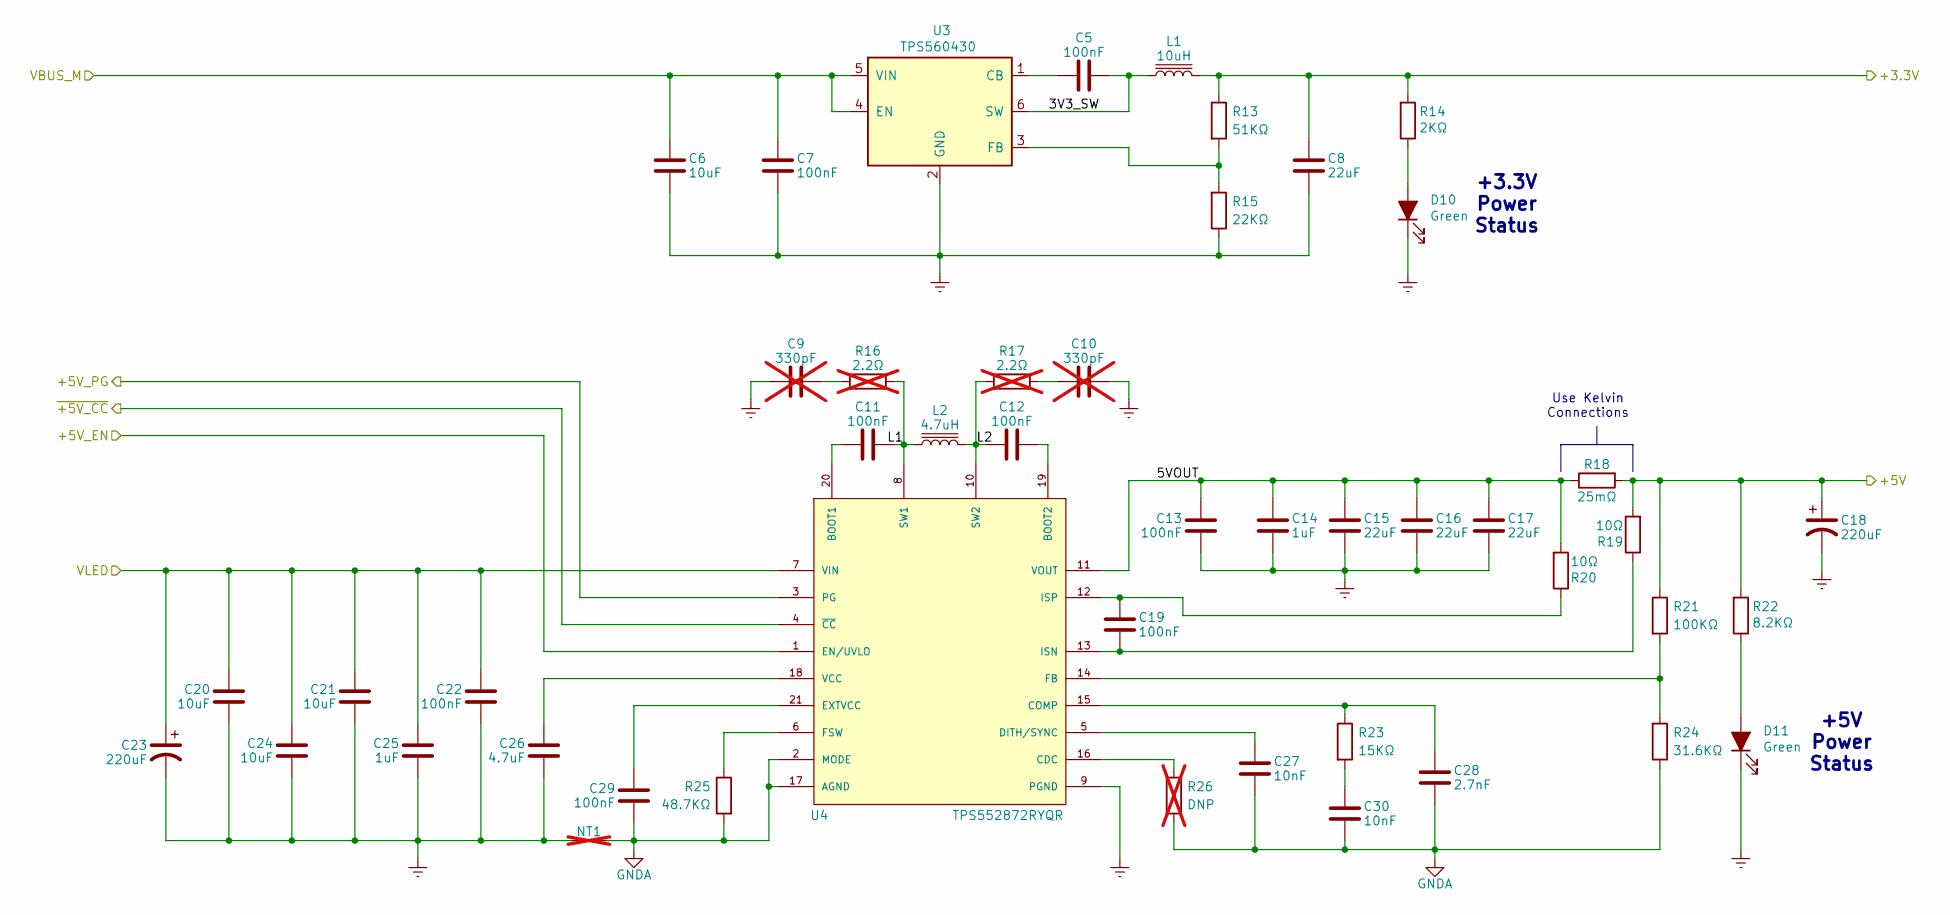
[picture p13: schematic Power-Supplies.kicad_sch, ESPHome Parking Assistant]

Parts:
C5, C7, C11, C12, C13, C19, C22, C29: 100nF; C_0402_1005Metric; Part Number CL05B104KB54PNC; LCSC C307331
C6, C20, C21, C24: 10uF; C_1206_3216Metric; Part Number CL31A106KBHNNNE; LCSC C13585
C8, C15, C16, C17: 22uF; C_0805_2012Metric; Part Number LMK212BJ226MG-T; LCSC C92814
C9, C10: 330pF; C_1206_3216Metric; Part Number CC1206JRNPO9BN331; LCSC C541477; not fitted
C14, C25: 1uF; C_0603_1608Metric; Part Number CL10A105KB8NNNC; LCSC C15849
C18, C23: 220uF; CP_Elec_8x10.5; Part Number EEEFK1V221P; LCSC C178562
C26: 4.7uF; C_0603_1608Metric; Part Number CL10A475KO8NNNC; LCSC C19666
C27, C30: 10nF; C_0402_1005Metric; Part Number CL05B103KB5NNNC; LCSC C15195
C28: 2.7nF; C_0402_1005Metric; Part Number CL05B272KB5NNNC; LCSC C84704
D10, D11: Green; LED_0603_1608Metric; Part Number F.0603.00025/P2-0603G1TS2-06T-002; LCSC C7496818
L1: 10uH; IND_VLCF4028T-100M1R0-2; Part Number VLCF4028T-100M1R0-2; LCSC C694593
L2: 4.7uH; L_Vishay_IHLP-2020; Part Number IHLP2020CZER4R7M11; LCSC C845007
NT1: NetTie-2_SMD_Pad0.5mm; not fitted
R13: 51KΩ; R_0402_1005Metric; LCSC C25794
R14: 2KΩ; R_0402_1005Metric; LCSC C4109
R15: 22KΩ; R_0402_1005Metric; LCSC C25768
R16, R17: 2.2Ω; R_1206_3216Metric; LCSC C104742; not fitted
R18: 25mΩ; R_0805_2012Metric; LCSC C2767472
R19, R20: 10Ω; R_0402_1005Metric; LCSC C25077
R21: 100KΩ; R_0402_1005Metric; LCSC C25741
R22: 8.2KΩ; R_0402_1005Metric; LCSC C36953
R23: 15KΩ; R_0402_1005Metric; LCSC C25539
R24: 31.6KΩ; R_0402_1005Metric; LCSC C226989
R25: 48.7KΩ; R_0402_1005Metric; LCSC C26981
R26: DNP; R_0402_1005Metric; not fitted
U3: TPS560430; SOT-23-6; Part Number TPS560430XDBVR; LCSC C524782
U4: TPS552872RYQR; VQFN21_RYQ_TEX; Part Number TPS552872RYQR; LCSC C22397842

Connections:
+3V3: C8.2, L1.2, R13.1, R14.2; also elsewhere on the board
+5V: C18.1, R18.2, R19.2, R21.1, R22.2; also elsewhere on the board
/ESP32-S3/+5V_EN: U4.1 (EN/UVLO); also elsewhere on the board
/ESP32-S3/+5V_PG: U4.3 (PG); also elsewhere on the board
/ESP32-S3/~+5V_CC: U4.4 (~CC); also elsewhere on the board
/Power Supplies/3V3_SW: C5.2, L1.1, U3.6 (SW)
/Power Supplies/5VOUT: C13.2, C14.1, C15.2, C16.2, C17.2, R18.1, R20.2, U4.11 (VOUT)
/Power Supplies/L1: C11.2, L2.1, R16.1, U4.8 (SW1)
/Power Supplies/L2: C12.1, L2.2, R17.2, U4.10 (SW2)
GND: C6.2, C7.1, C8.1, C9.1, C10.2, C13.1, C14.2, C15.1, C16.1, C17.1, C18.2, C20.2, C21.2, C22.1, C23.2, C24.2, C25.2, C26.1, D10.1 (K), D11.1 (K), NT1.1, R15.1, U3.2 (GND), U4.9 (PGND); also elsewhere on the board
GNDA: C27.1, C28.1, C29.1, C30.1, NT1.2, R24.1, R25.2, R26.2, U4.2 (MODE), U4.17 (AGND)
unnamed: C9.2, R16.2
unnamed: C10.1, R17.1
unnamed: C30.2, R23.2
unnamed: D10.2 (A), R14.1
unnamed: D11.2 (A), R22.1
unnamed: C5.1, U3.1 (CB)
unnamed: R13.2, R15.2, U3.3 (FB)
unnamed: C11.1, U4.20 (BOOT1)
unnamed: C12.2, U4.19 (BOOT2)
unnamed: R26.1, U4.16 (CDC)
unnamed: C28.2, R23.1, U4.15 (COMP)
unnamed: C27.2, U4.5 (DITH/SYNC)
unnamed: C29.2, U4.21 (EXTVCC)
unnamed: R21.2, R24.2, U4.14 (FB)
unnamed: R25.1, U4.6 (FSW)
unnamed: C19.1, R19.1, U4.13 (ISN)
unnamed: C19.2, R20.1, U4.12 (ISP)
unnamed: C26.2, U4.18 (VCC)
VBUS_M: C6.1, C7.2, U3.4 (EN), U3.5 (VIN); also elsewhere on the board
VLED: C20.1, C21.1, C22.2, C23.1, C24.1, C25.1, U4.7 (VIN); also elsewhere on the board

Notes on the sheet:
+5V Power Status
+3.3V Power Status
Use Kelvin Connections

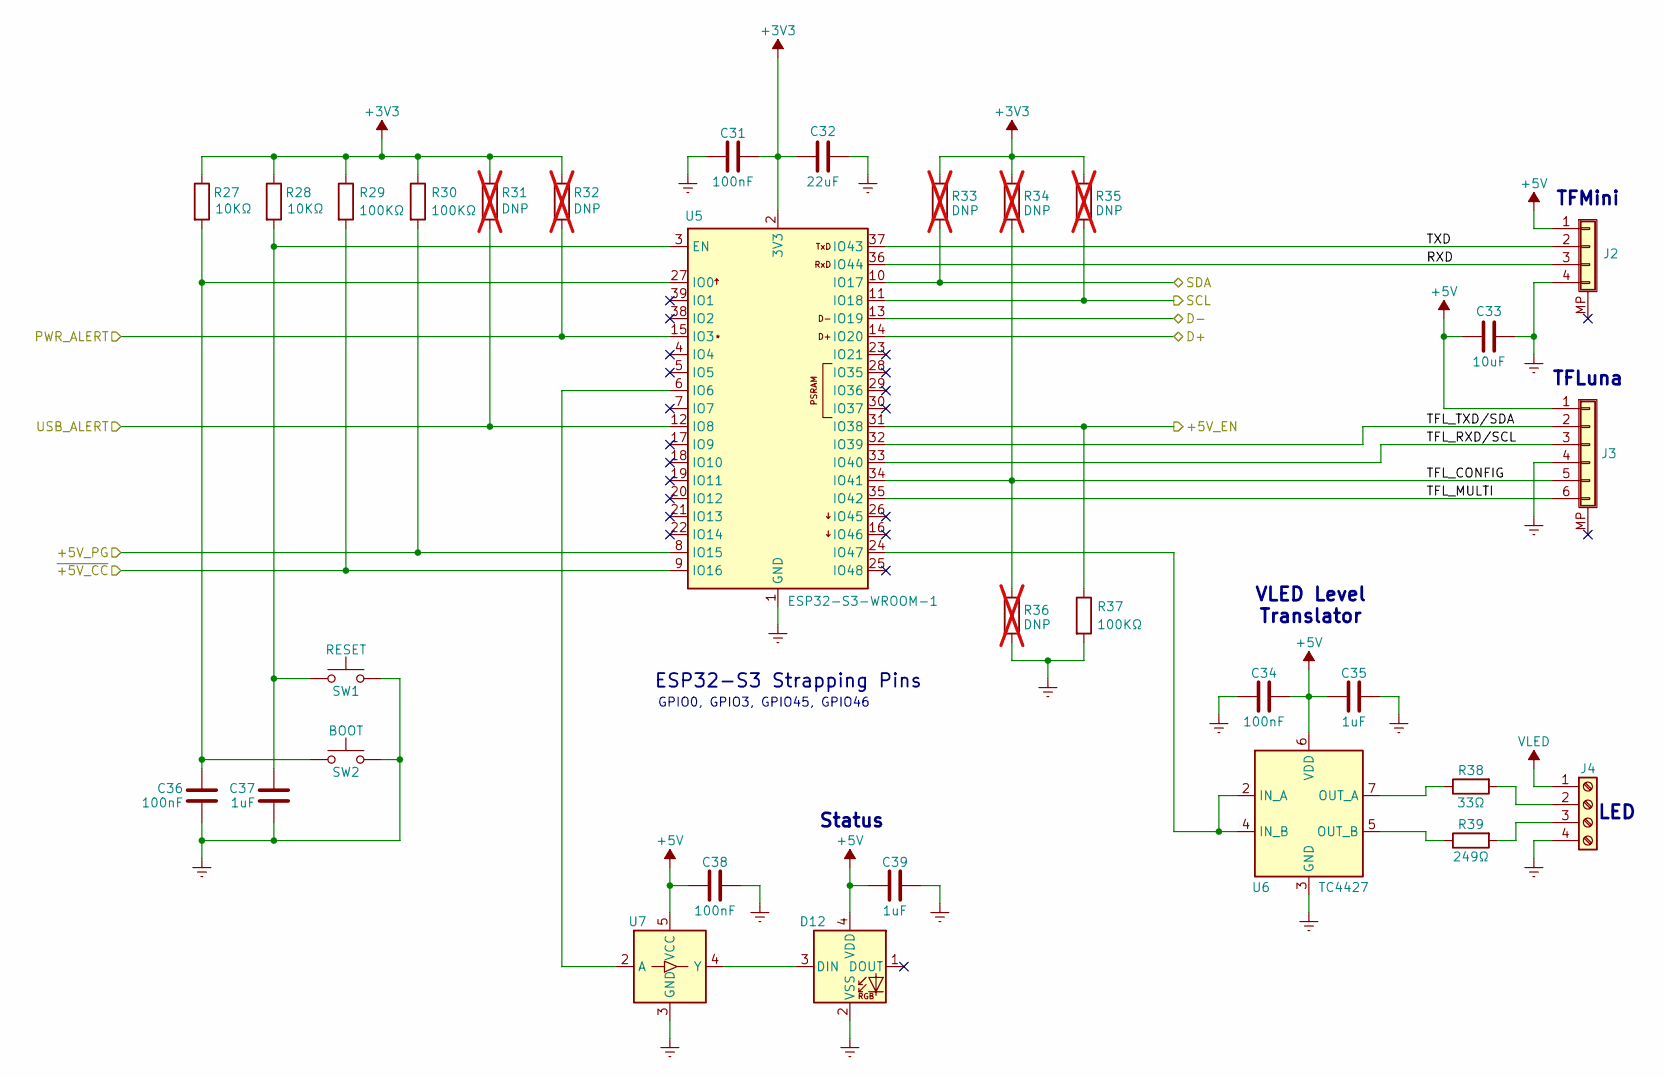
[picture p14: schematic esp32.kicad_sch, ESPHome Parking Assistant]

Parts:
C31, C34, C36, C38: 100nF; C_0402_1005Metric; Part Number CL05B104KB54PNC; LCSC C307331
C32: 22uF; C_0805_2012Metric; Part Number LMK212BJ226MG-T; LCSC C92814
C33: 10uF; C_1206_3216Metric; Part Number CL31A106KBHNNNE; LCSC C13585
C35, C37, C39: 1uF; C_0603_1608Metric; Part Number CL10A105KB8NNNC; LCSC C15849
D12: WS2812B-2020; LED_WS2812B-2020_PLCC4_2.0x2.0mm; Part Number WS2812B-2020; LCSC C965555
J2: 533980471; Molex_PicoBlade_53398-0471_1x04-1MP_P1.25mm_Vertical; Part Number 533980471; LCSC C17617036
J3: 533980671; Molex_PicoBlade_53398-0671_1x06-1MP_P1.25mm_Vertical; Part Number 533980671; LCSC C277393
J4: Screw_Terminal_01x04; PhoenixContact_MC_1,5_4-GF-3.5_1x04_P3.50mm_Horizontal_Thre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; Part Number 1843813
R27, R28: 10KΩ; R_0402_1005Metric; LCSC C25531
R29, R30, R37: 100KΩ; R_0402_1005Metric; LCSC C25741
R31, R32, R33, R34, R35, R36: DNP; R_0402_1005Metric; not fitted
R38: 33Ω; R_1210_3225Metric; LCSC C105005
R39: 249Ω; R_1210_3225Metric; LCSC C874850
SW1: RESET; SW_SPST_B3U-1000P-B; Part Number B3U-1000P; LCSC C231329
SW2: BOOT; SW_SPST_B3U-1000P-B; Part Number B3U-1000P; LCSC C231329
U5: ESP32-S3-WROOM-1; Part Number ESP32-S3-WROOM-1-N8R8; LCSC C2913201
U6: TC4427; SOIC-8_3.9x4.9mm_P1.27mm; Part Number TC4427VOA; LCSC C636893
U7: SN74LV1T34DBV; SOT-23-5; Part Number SN74LV1T34DBV; LCSC C100024

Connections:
+3V3: C31.2, C32.1, R27.1, R28.1, R29.1, R30.1, R31.1, R32.1, R33.1, R34.1, R35.1, U5.2 (3V3); also elsewhere on the board
+5V: C33.1, C34.2, C35.2, C38.1, C39.1, D12.4 (VDD), J2.1, J3.1, U6.6 (VDD), U7.5 (VCC); also elsewhere on the board
/ESP32-S3/+5V_EN: R37.1, U5.31 (IO38); also elsewhere on the board
/ESP32-S3/+5V_PG: R30.2, U5.8 (IO15); also elsewhere on the board
/ESP32-S3/D+: U5.14 (IO20); also elsewhere on the board
/ESP32-S3/D-: U5.13 (IO19); also elsewhere on the board
/ESP32-S3/PWR_ALERT: R32.2, U5.15 (IO3); also elsewhere on the board
/ESP32-S3/RXD: J2.3, U5.36 (IO44)
/ESP32-S3/SCL: R35.2, U5.11 (IO18); also elsewhere on the board
/ESP32-S3/SDA: R33.2, U5.10 (IO17); also elsewhere on the board
/ESP32-S3/TFL_CONFIG: J3.5, R34.2, R36.1, U5.34 (IO41)
/ESP32-S3/TFL_MULTI: J3.6, U5.35 (IO42)
/ESP32-S3/TFL_RXD/SCL: J3.3, U5.33 (IO40)
/ESP32-S3/TFL_TXD/SDA: J3.2, U5.32 (IO39)
/ESP32-S3/TXD: J2.2, U5.37 (IO43)
/ESP32-S3/USB_ALERT: R31.2, U5.12 (IO8); also elsewhere on the board
/ESP32-S3/~+5V_CC: R29.2, U5.9 (IO16); also elsewhere on the board
GND: C31.1, C32.2, C33.2, C34.1, C35.1, C36.1, C37.2, C38.2, C39.2, D12.2 (VSS), J2.4, J3.4, J4.4, R36.2, R37.2, SW1.1, SW2.1, U5.1 (GND), U5.40 (GND), U5.41 (GND), U6.3 (GND), U7.3 (GND); also elsewhere on the board
unnamed: D12.3 (DIN), U7.4 (Y)
unnamed: J4.2, R38.2
unnamed: J4.3, R39.2
unnamed: C37.1, R28.2, SW1.2, U5.3 (EN)
unnamed: C36.2, R27.2, SW2.2, U5.27 (IO0)
unnamed: U5.6 (IO6), U7.2 (A)
unnamed: U5.24 (IO47), U6.2 (IN_A), U6.4 (IN_B)
unnamed: R38.1, U6.7 (OUT_A)
unnamed: R39.1, U6.5 (OUT_B)
VLED: J4.1; also elsewhere on the board

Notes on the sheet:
LED
GPIO0, GPIO3, GPIO45, GPIO46
TFLuna
TFMini
VLED Level Translator
ESP32-S3 Strapping Pins
Status

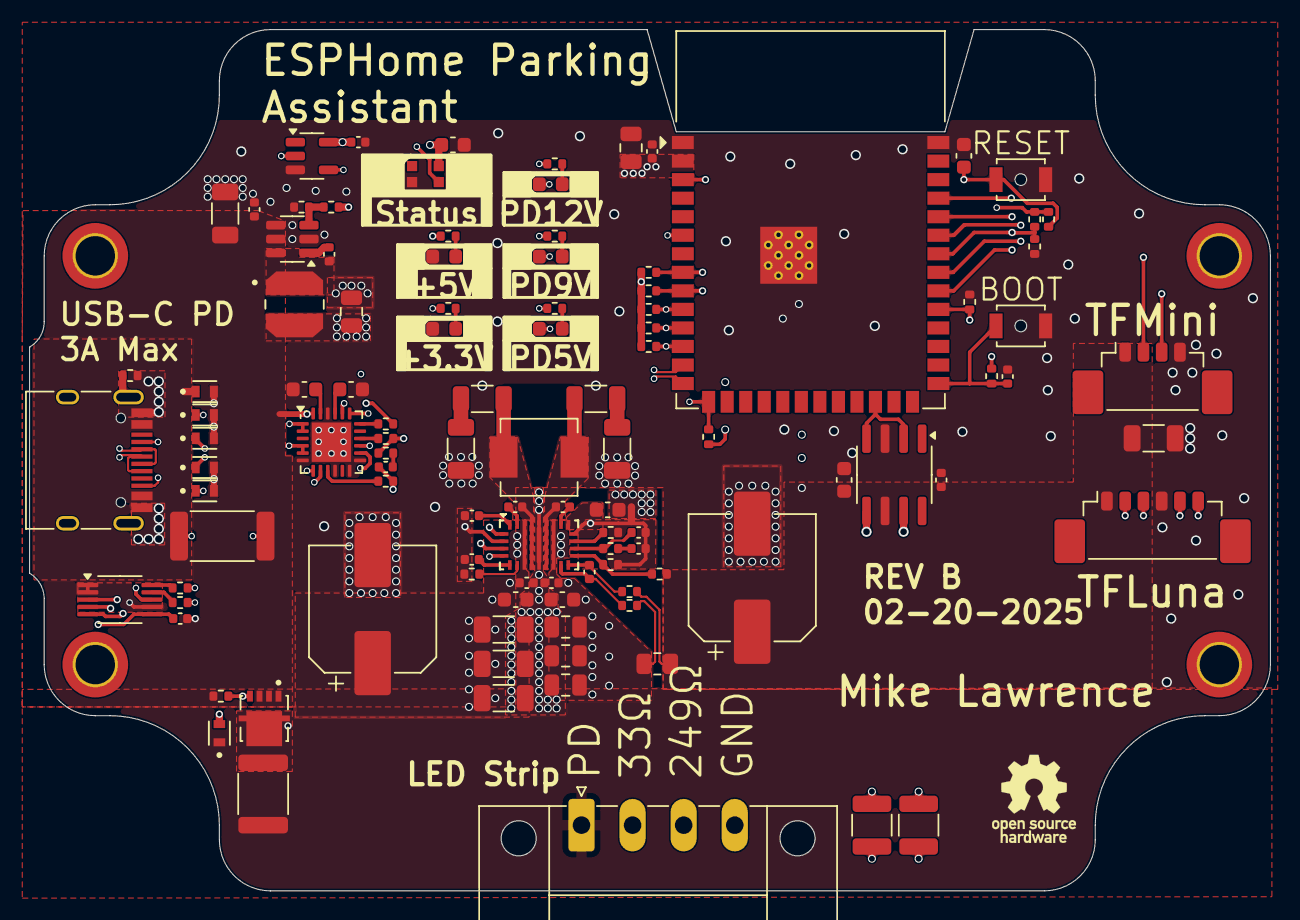
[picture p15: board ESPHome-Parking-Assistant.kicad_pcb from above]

Board: 4 copper layers, 85.0 x 59.0 mm, 114 parts (1 on the bottom side), 72 nets.

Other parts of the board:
MH1, MH2, MH3, MH4: MountingHole_2.7mm_M2.5_ISO7380_Pad_TopBottom
TEXT1: OSHW-Logo_5.7x6mm_SilkScreen
TEXT2: OSHW-Logo2_24.3x20mm_SilkScreen

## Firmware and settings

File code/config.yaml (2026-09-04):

substitutions:
  name: "parking-assistant"
  friendly_name: "Parking Assistant"
  company_name: "Mike Lawrence"
  # To enable floor mode (sensor pointed at the floor) set door_distance to '0'
  #   When position > ${floor_distance} + ${tolerance} the space is considered empty
  #   To leave the empty state, ${floor_distance} + ${tolerance} > position > ${floor_trigger}
  #     If position bypasses this range, most likely it is a person walking in front of the sensor
  # If door_distance is not zero then sensor is pointing at a garage door
  hysterysis: "2.5"             # amount of position change to prevent bouncing between states in (cm)
  tolerance: "10"               # +/- tolerance in (cm) for changing states
  door_distance: "0"            # distance (cm) to garage door
  floor_distance: "345.5"       # distance (cm) to garage floor, should be close to the average value
  floor_trigger: "275"          # measurements in this range will trigger state machine, must be greater than floor_distance - tolerance
  park_distance: "104.0"        # max distance (cm) where car is considered parked (closest to the garage door)
  park_tolerance: "10.0"        # +/- tolerance (cm) around park_distance still considered parked

esphome:
  name: ${name}
  friendly_name: ${friendly_name} 
  name_add_mac_suffix: false
  project:
    name: Mike Lawrence.${friendly_name}
    version: 0.2.0
  on_boot:
    then:
      - light.turn_on:
          id: led_strip
          brightness: 100%
          effect: "Parking Bar"

esp32:
  board: esp32-s3-devkitc-1
  variant: ESP32S3
  flash_size: 8MB
  framework:
    type: esp-idf

psram:
  mode: octal
  speed: 80MHz

external_components:
  - source: github://mikelawrence/esphome-component-tfmini@2026.8.0
  - source: github://mikelawrence/esphome-component-stusb4500@2026.8.0

esp32_ble_tracker:
  scan_parameters:
    # We currently use the defaults to ensure Bluetooth
    # can co-exist with WiFi In the future we may be able to
    # enable the built-in coexistence logic in ESP-IDF
    active: true

bluetooth_proxy:
  active: true

# Disable logging, this will greatly reduce glitching on the light bar
logger:
  level: DEBUG
  logs:
    tfmini.sensor: ERROR

debug:
  update_interval: 60s

# Enable Home Assistant API
api:
  encryption:
    key: mpFBP+apdcrB3yCqG6ieFTunwUGe31kPHWxF9l2Ncsk=

# Enable Over-the-Air updates
ota:
  id: my_ota
  platform: esphome
  password: !secret ota_password

wifi:
  ssid: !secret wifi_ssid
  password: !secret wifi_password

globals:
  # Garage Door Closed = 0, Garage Door Open = 10, Car Parking Zone = 20, Car Parked = 30, Car Over = 40
  - id: state
    type: int
  - id: last_state
    type: int
  - id: distance
    type: float

time:
  - platform: homeassistant
    id: homeassistant_time
    on_time: 
      - seconds: 0
        minutes: 0
        hours: 0
        then:
          - lambda: "id(pcb_power).reset_energy_counters();"

# config the UART for the TFMini sensor
uart:
  - id: tfmini_uart
    tx_pin: GPIO43
    rx_pin: GPIO44
    baud_rate: 115200
    data_bits: 8
    parity: NONE
    stop_bits: 1

i2c:
  sda: GPIO17
  scl: GPIO18
  frequency: 400kHz

power_supply:
  - id: 'power_supply_5V'
    pin: GPIO38
    enable_on_boot: true
    enable_time: 1s

stusb4500:
    id: pd_controller
    alert_pin: GPIO8
    # flash_nvm: true
    # # Use this section for 5V LEDs.
    # i_snk_pdo1: 3.00A
    # snk_pdo_numb: 1
    # # End 5V LED section
    # Use this section for 12V LEDs
    snk_pdo_numb: 2
    i_snk_pdo1: 3.00A
    v_snk_pdo2: 9.00V
    i_snk_pdo2: 3.00A
    v_snk_pdo3: 12.00V
    i_snk_pdo3: 3.00A
    # End 12V LED section
    req_src_current: true
    # power_only_above_5v: true
    gpio_cfg: SW_CTRL_GPIO
    usb_comms_capable: true

button:
  - platform: restart
    name: "Restart"
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

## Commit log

2025-02-22 Just beginning the commit process. More to come soon.
    [1812_Fuse.STEP, 7673.TPS552872-Design Calculation Tool-V1.0.xlsx, ESPHome-Parking-Assistant.kicad_pcb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]
2025-02-23 Add PCB section and edit Enclosure section
2025-02-23 Revert "Add PCB section and edit Enclosure section"
    This reverts commit f3cafefe5a9607d9db253730a9622a0c797a1213.
2025-02-25 Add note about Homer Assistant Garage Door Sensor and how to remove if you don't have it.
2025-02-25 Change R23 to 15KΩ
    [ESPHome-Parking-Assistant.kicad_pcb, Power-Supplies.kicad_sch, bom.csv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]
2025-02-25 Fix last commit. R26 is DNP and R23 changed to 15kΩ.
    [ESPHome-Parking-Assistant.kicad_pcb, Power-Supplies.kicad_sch, esp32.kicad_sch]
2025-02-25 Add link to schematic in pdf form and some notes about the schematic.
2025-02-25 Update README.md
    Make PCB image larger
2025-02-25 Add PCB STL file
2025-03-04 Fixed incorrectly marked Status LEDs on PCB.
    New notes on LED status in README.
    Updated config.yaml based on more testing in the lab.
    [ESPHome-Parking-Assistant.kicad_pcb]
2025-04-11 Update interactive BOM and README.
    [7673.TPS552872-Design Calculation Tool-V1.0.xlsx]
2026-09-04 Update to KiCad 10.0.6 No functional changes to design
    [ESPHome-Parking-Assistant.kicad_pcb, ESPHome-Parking-Assistant.kicad_sch, Power-Supplies.kicad_sch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]
2026-09-04 Major update Add BLE tracker and proxy. Remove Garage Open template sensor. Update TFMini Sensor Filters and update rate. Support RGB Led changes from Hom Assistant. Massive update to Parking State M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
